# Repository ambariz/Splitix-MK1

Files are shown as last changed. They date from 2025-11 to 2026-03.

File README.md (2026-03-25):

# Splitix MK1

A custom, split mechanical keyboard with modular design, it can be used as a split keyboard or joined together and used like a regular keyboard.

Inspired by the split, futuristic keyboard used by Tony Stark in Iron Man, this project explores that concept in a practical, physical form. Splitix MK1 is the first iteration, focused on building a solid foundation before moving towards more advanced designs.

It features a custom PCB designed in KiCad, per-key NeoPixel RGB lighting, an integrated display, and a rotary encoder. The board also includes battery support with voltage monitoring.

The design includes a fully hand-routed PCB with custom footprints and a skeletal 3D-printed case that enhances the lighting and overall aesthetic.

This project is part of a larger journey toward creating a more advanced, Iron Man - inspired keyboard in future iterations.

| Left Build (without case) | Right Build (without case) |
|---|---|
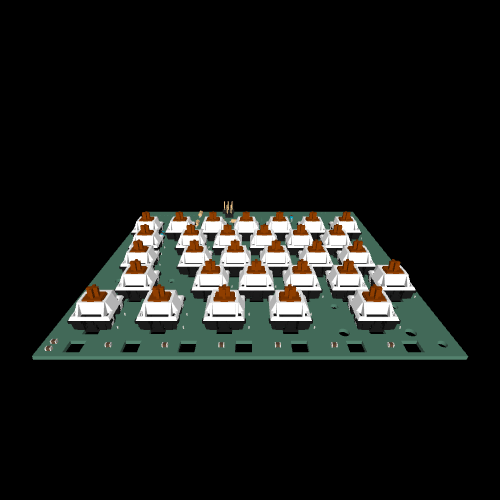
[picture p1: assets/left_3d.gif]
left build
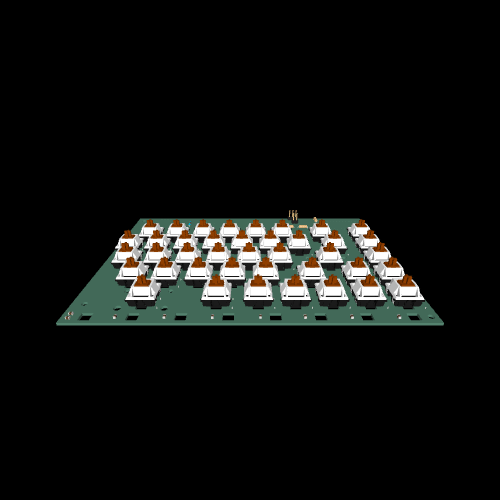
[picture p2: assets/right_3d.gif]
right build
|  |  |

# Features

- Split / Modular (can be joined and used as a single keyboard)
- Wireless (Bluetooth via NRF52840)
- ZMK Firmware
- Hotswappable
- Per-key NeoPixel RGB
- Rotary Encoder
- Integrated Display
- Skeletal 3D-printed case (M3 mount)

## CAD

> **Note:**
> This is a skeletal open case design that includes only the base structure. It is designed to hold the PCB securely while keeping the overall form minimal and exposing the components, especially the RGB lighting. The open design enhances visibility of the internals and lighting, while support pillars and M3 mounts provide the necessary structural stability.

| Left | Right |
|---|---|
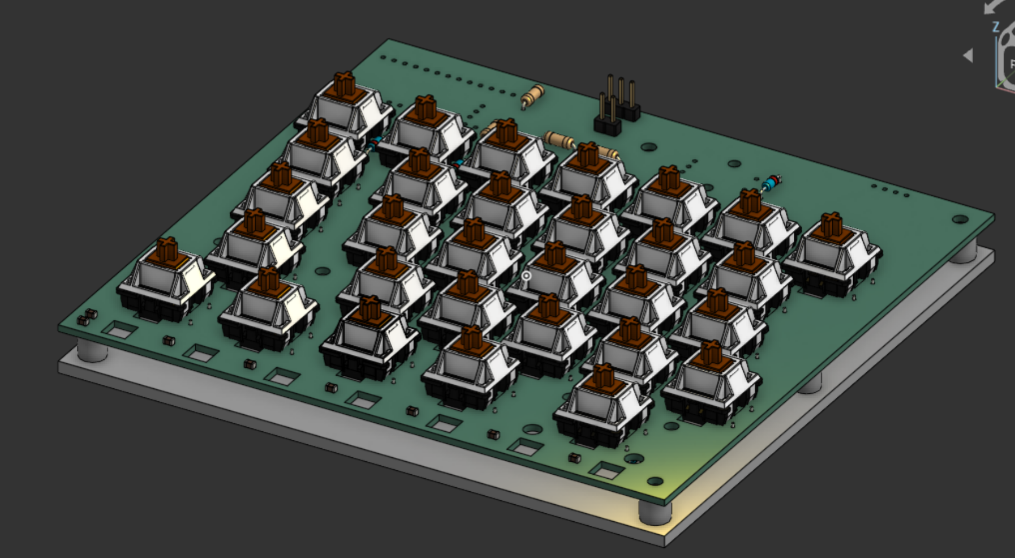
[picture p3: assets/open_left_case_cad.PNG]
case left
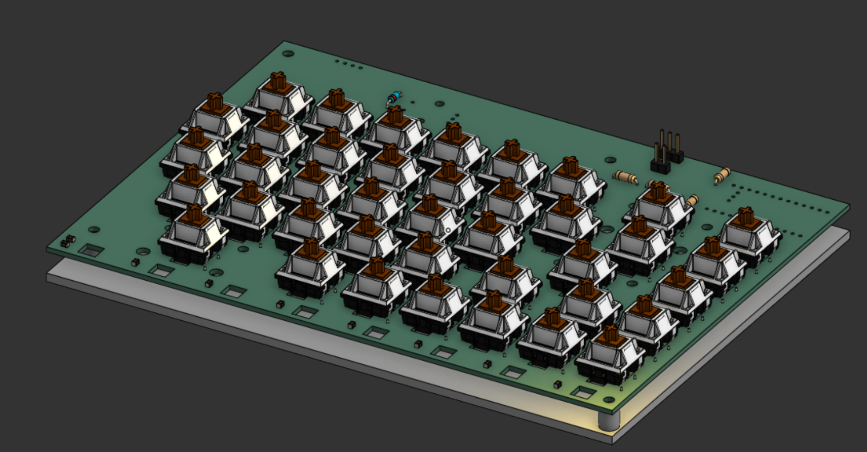
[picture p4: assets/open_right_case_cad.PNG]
case right
|  |  |
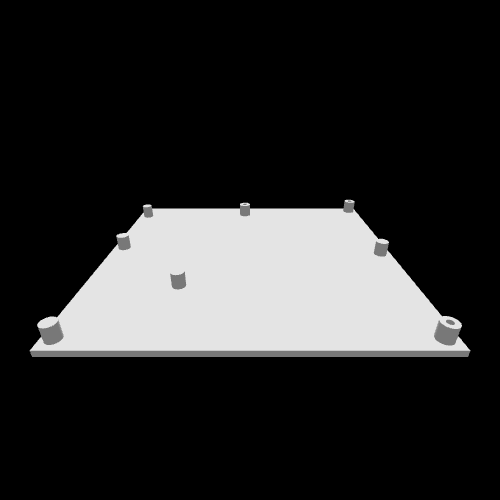
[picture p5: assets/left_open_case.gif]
case left
|  | case right |
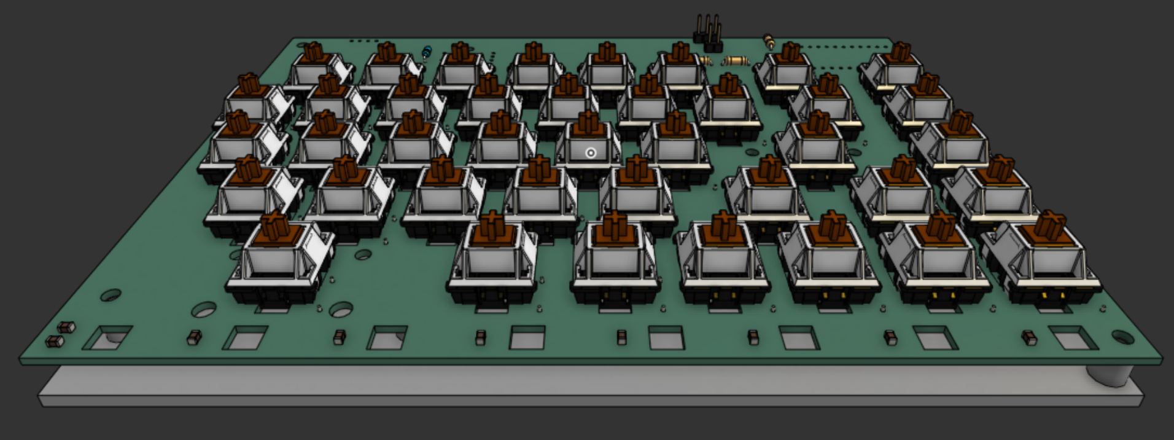
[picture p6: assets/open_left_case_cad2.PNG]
case left
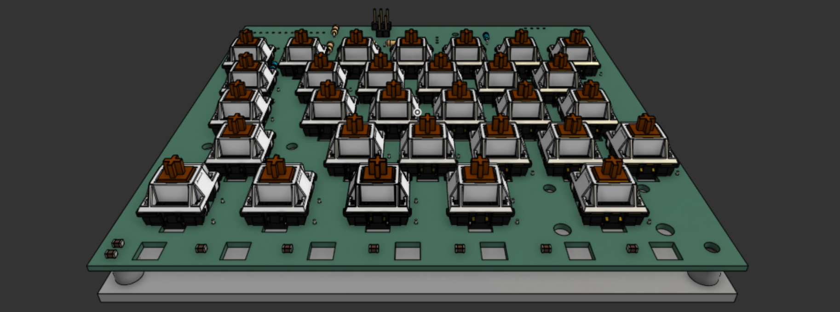
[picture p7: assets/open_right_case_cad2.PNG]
case right
|  |  |

## PCB

> **Note:**  
> The PCB is designed as a single board with mouse bite connections, allowing it to be snapped into left and right halves after fabrication.

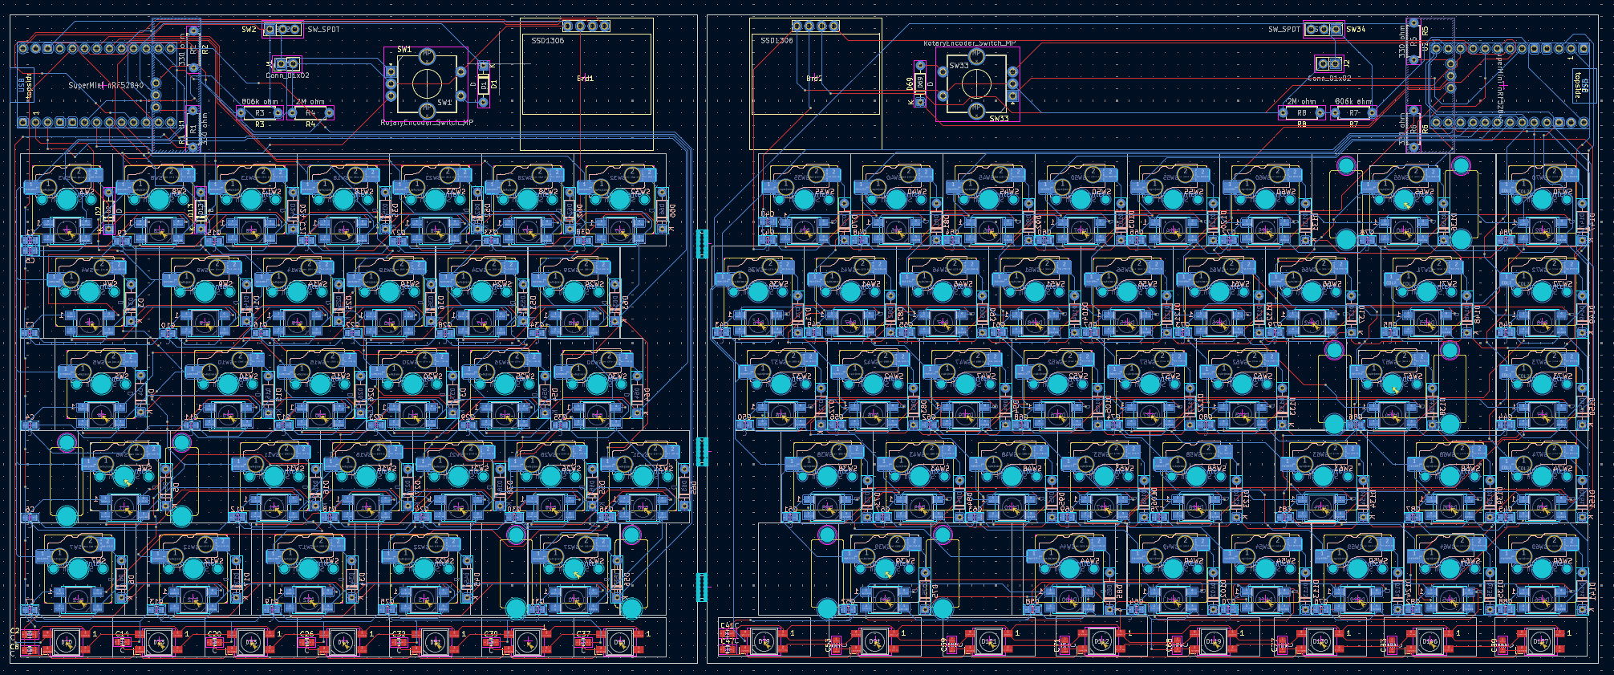
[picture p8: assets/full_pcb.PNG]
PCB


## Schematic

> **Note:**  
> The preview images may be scaled down and lose detail. Use the PDF below for a clear, full-resolution view.

<p align="center">
  <a href="https://raw.githubusercontent.com/ambariz/Splitix-MK1/main/pcb/Splitix%20MK1.pdf">
    
  </a>
</p>

| Left | Right |
|---|---|
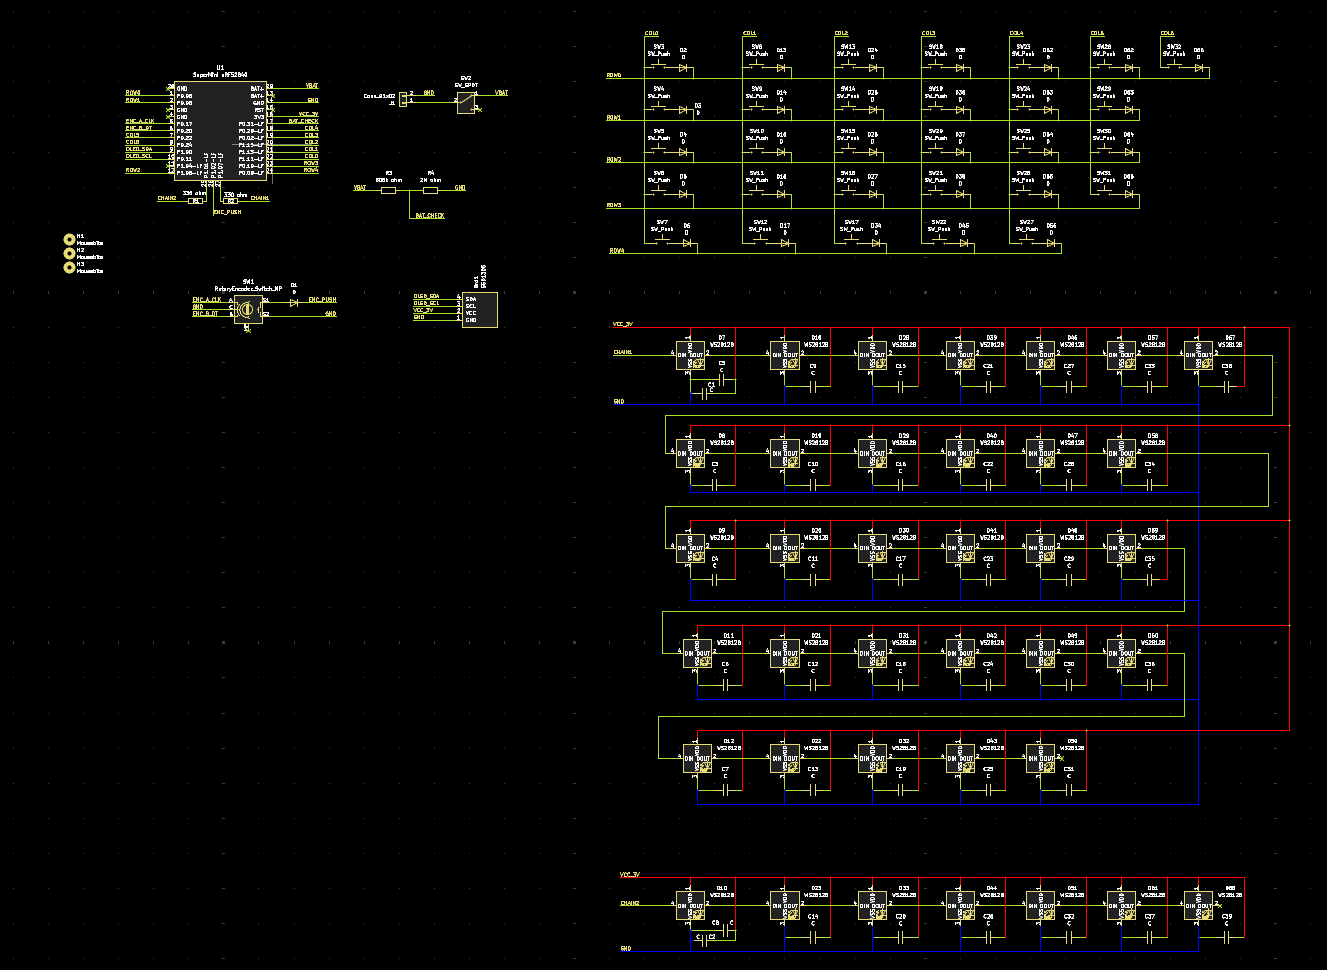
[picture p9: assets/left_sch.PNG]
Left schematic
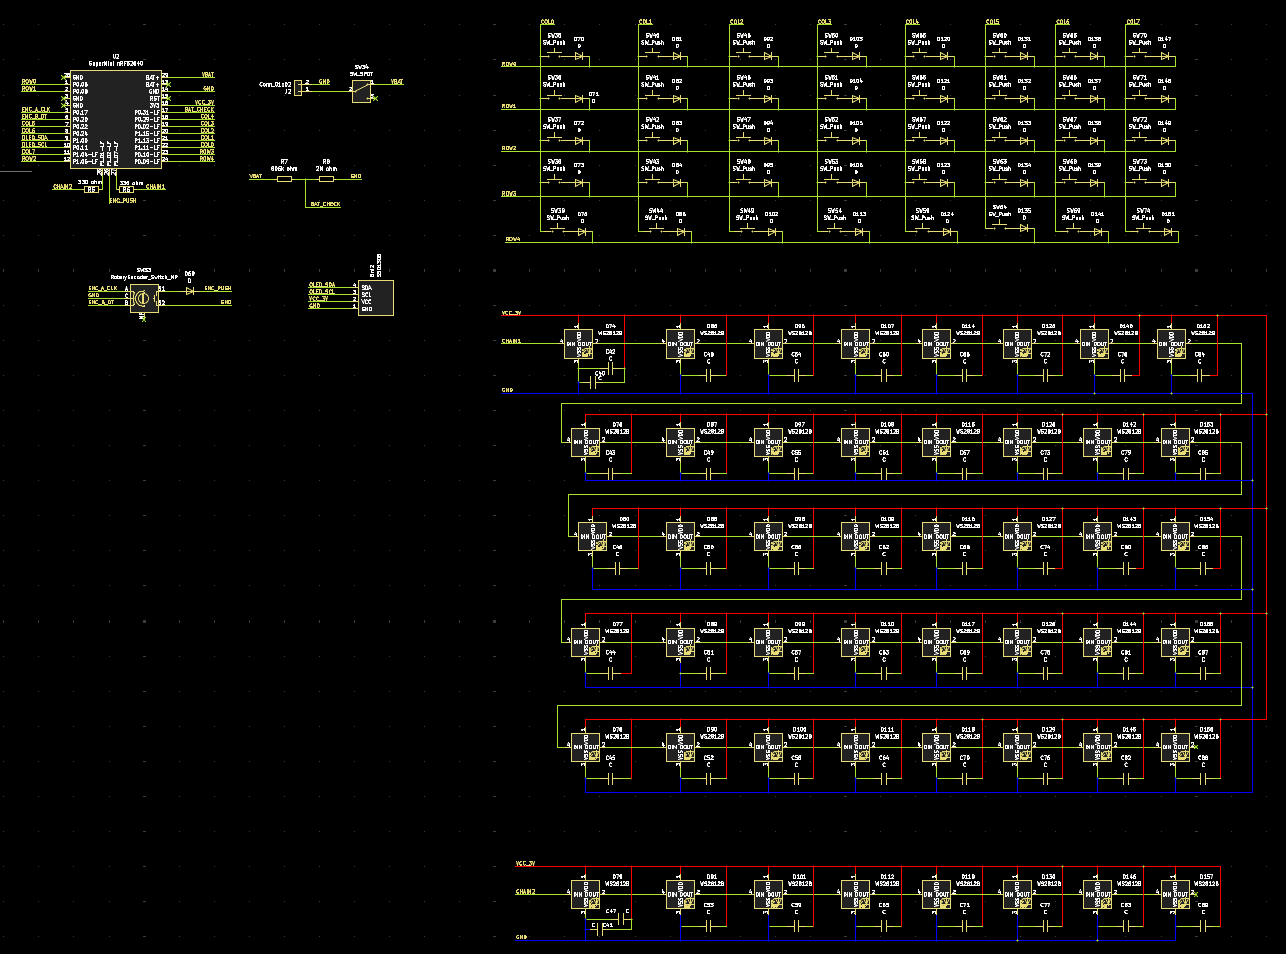
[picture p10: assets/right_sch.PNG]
Right schematic
|  |  |

## ZMK Keymap

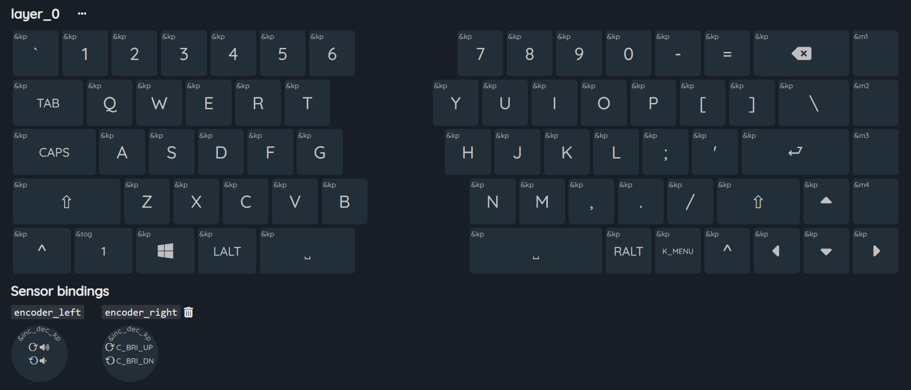
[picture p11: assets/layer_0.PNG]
layer 0

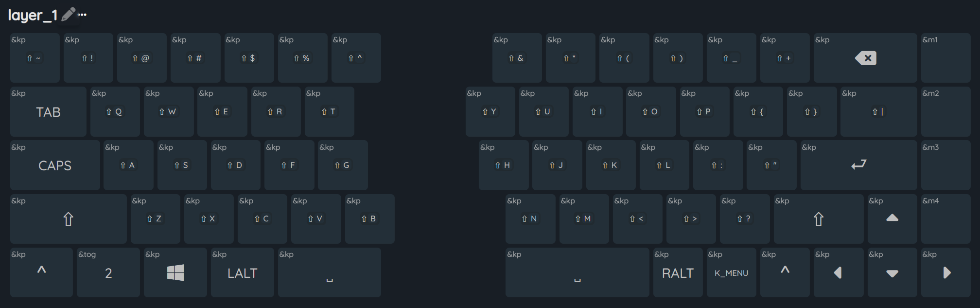
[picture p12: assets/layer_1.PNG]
layer 1

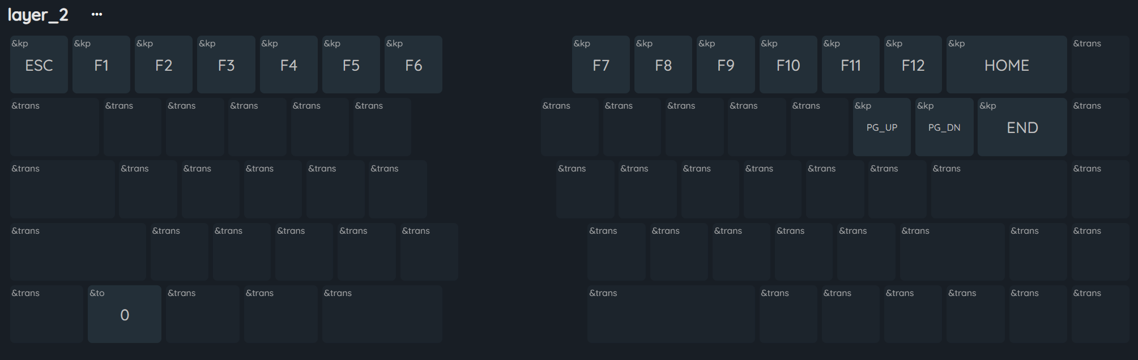
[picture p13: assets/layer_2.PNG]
layer 2


## BOM

| Product | Quantity | Source | Price (INR) | Link |
| :--- | :--- | :--- | :--- | :--- |
| ProMicro NRF52840 | 2 | Robu | 1516 | [Product Link](https://robu.in/product/promicro-nrf52840-development-board/) <br> OR <br> [Product Link](https://robu.in/product/pro-micro-nrf52840-development-board-compatible-with-nicenano-v2-0/) <br> OR <br> [Product Link](https://probots.co.in/pro-micro-nrf52840-development-board-compatible-with-nice-nano-v2-0.html)|
| Hongyan EC11H 7CE20P1ZD20 | 2 | Robu | 110 | [Product Link](https://robu.in/product/hongyan-ec11h-7ce20p1zd20-rotary-encoder-with-push-button-switch-vertical-plug-in-5-pin/) |
| EC11 Rotary Encoder Knob (D-shaft) | 2 | Robu | 58 | [Product Link](https://robu.in/product/potentiometer-knob-rotary-switch-cap-black-color-pack-of-5-pcs/) |
| 0.96" / 1.3" I2C OLED | 2 | Robu | 312 | [Product Link](https://robu.in/product/0-96-inch-yellow-yellow-blue-oled-lcd-led-display-module/) <br> OR <br> [Product Link](https://robu.in/product/1-3-inch-i2c-iic-4-pin-oled-display-module-with-vcc-gnd-blue/) |
| WS2812B 16-LED Ring (Neopixel) | 6 (rings) / 90 (individual) | Robu / Ktron | 546 | [Product Link](https://robu.in/product/16bit-ws2812b-5050-rgb-led-built-in-full-color-driving-lights-circular-development-board/) <br> OR <br> [Product Link](https://www.ktron.in/product/ws2812b-rgb-smd-5050-led/?v=c86ee0d9d7ed) |
| 330Ω Resistor | 4 | Robu | 1.16 | [Product Link](https://robu.in/product/330-ohm-0-25w-metal-film-resistor-pack-of-100/) |
| 806kΩ Resistor | 2 | Robu | 1.24 | [Product Link](https://robu.in/product/mcmf0w4ff8203a50-multicomp-pro-metal-film-resistor-820kohm-250mw-1/) |
| 2MΩ Resistor | 2 | Amazon | 198 | [Product Link](https://www.amazon.in/Electronic-Spices-Tolerance-Through-Resistors/dp/B0BDDRD9DN) |
| 100µF 0805 Capacitor | 6 | Robu | 270 | [Product Link](https://robu.in/product/cl21a107mqynnwe-samsang-6-3v-100uf-x5r-%C2%B120-0805-multilayer-ceramic-capacitors-mlcc-smd-smt-rohs/) |
| 0.1µF (100nF) 0805 Capacitor | 95 | Robu | 145.35 | [Product Link](https://robu.in/product/cc0805jrx7r9bb104-yageo-smd-multilayer-ceramic-capacitor-0-1-%C2%B5f-50-v-0805-2012-metric-%C2%B1-5-x7r-cc-series/) |
| Mechanical Key Switches (MX Compatible) | 75 | StacksKB | 2398 | [Product Link](https://stackskb.com/store/akko-creamy-cyan-switch-pack-of-45-pre-order/) |
| Keycaps (MX Compatible) | 1 set | StacksKB | 1299 | [Product Link](https://stackskb.com/store/veekos-gradient-keycaps-cherry-profile-135-keys/) |
| Hotswap Sockets (Kailh MX) | 75 | StacksKB | 750 | [Product Link](https://stackskb.com/store/ttc-pokayoke-hotswap-sockets-v2-10000-cycles/) |
| 1N4148 Diodes | 80 | StacksKB | 120 | [Product Link](https://stackskb.com/store/1n4148-through-hole-diode/) |
| Li-ion Battery 1500mAh | 2 | Robu | 502 | [Product Link](https://robu.in/product/nova-803450-1500mah-3-7v-lipo-battery-pack/) |
| JST-PH 2-pin Connector | 2 | Robu | 2.84 | [Product Link](https://robu.in/product/jst-sh-2-pin-connector-2mm-pitch/) |
| TP4056 Type-C Charging Module | 2 | Robu | 28 | [Product Link](https://robu.in/product/tp4056-1a-li-ion-lithium-battery-charging-module-with-current-protection-type-c/) |
| Slide Switch SS-12D03 | 2 | Robu | 6 | [Product Link](https://robu.in/product/slide-switch-ss-12d03-1p2t/) |
| Keyboard PCB Left | 5 | Robu | 2500 | [Product Link](https://robu.in/product/online-pcb-manufacturing-service/) |
| Keyboard PCB Right | 5 | Robu | 2500 | [Product Link](https://robu.in/product/online-pcb-manufacturing-service/) |
| Keyboard Case (3D Print) | 1 | Robu | 530 | [Product Link](https://robu.in/product/3d-printing-service/) |
| Screws | 15 | Generic |  | Any M3 screws will work |

---

### Total Cost (Maximum)

**₹13,793.59**

> Includes all components for full build.

---

# Mechanical Keyboard Keycap Profiles
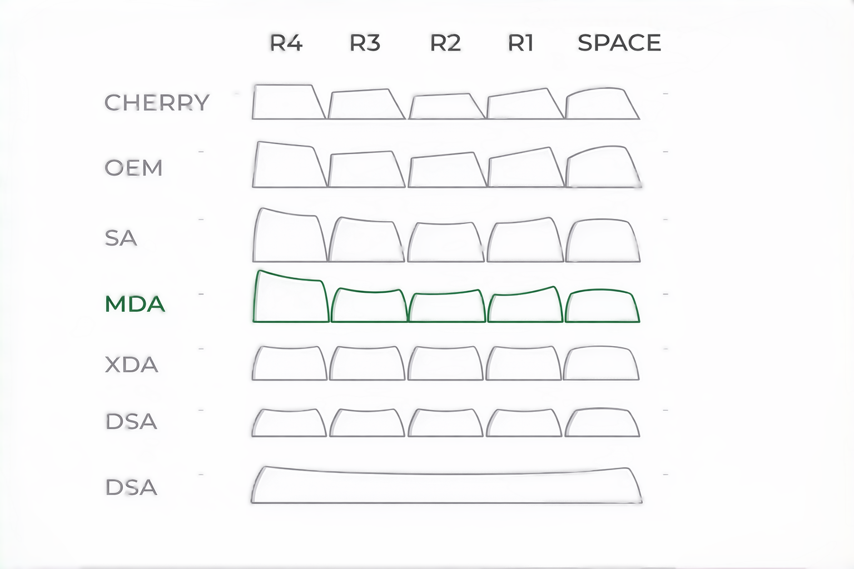
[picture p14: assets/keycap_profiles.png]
Mechanical Keyboard Keycap Profiles Comparison


---

### Quick Comparison
| Profile | Key Features | Best Used For |
| :--- | :--- | :--- |
| **Cherry** | Ergonomic height, reduces accidental touches. | All-around daily use. |
| **OEM** | Standard height, crisp typing sound. | Linear switches and gaming. |
| **XDA** | Uniform height, large surface area. | Tactile switches, long typing sessions. |
| **DSA** | Very low, uniform height. | Minimalist builds and customization. |
| **MDA** | Stepped uniform profile, textured feel. | Ergonomic long-form typing. |
| **SA** | Tallest profile, spherical sculpt. | Aesthetics and deep sound (requires wrist rest). |

---

> ### Note:
- **Tall Profiles (SA):** Better acoustics and aesthetics, but poor ergonomics without a wrist rest.  
- **Flat Profiles (XDA, DSA):** Easier to customize looks, but higher chance of mistyping.  
- **Sculpted Profiles (Cherry, OEM, MDA):** Best for typing speed and overall accuracy.  

---

# Keyswitch Selection Guide

| Type | Characteristics | Best For |
| :--- | :--- | :--- |
| **1️⃣ Linear** | Very smooth, no bump. Quiet unless bottom-out → nice thock | Gaming + smooth typing |
| **2️⃣ Tactile** | Noticeable bump mid-press. Balanced sound + feel | Typing |
| **3️⃣ Clicky** | Loud click + tactile bump. Very audible → polarizing | Enthusiasts who love feedback |
| **4️⃣ Low Profile** | Short travel → less thock. More functional than aesthetic | Portable/compact builds |
| **5️⃣ Silent Switches** | Dampened + muted. Almost no sound → office safe | Office environments |  

marbastlib
keyswitch kicad library
keyboard footprints placer
fabrucatuib toolkit

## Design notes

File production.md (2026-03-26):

# Production - Splitix MK1

## Production Files

### PCB (Gerbers)

* `gerber_left.zip` – Left half PCB
* `gerber_right.zip` – Right half PCB
* `gerber_full.zip` – Panelized full PCB

### Case (3D Models)

* `left_open_case.3mf` / `left_open_case.stl`
* `right_open_case.3mf` / `right_open_case.stl`
* `full_open_case.3mf` / `full_open_case.stl`

---

## Which Files Should You Use?

### PCB

> *NOTE:*
> full gerber or left and right gerber costs will be same. full gerber got mousebites, you can easily break in to left and right pcb.

* Printing seperately or any one side → `gerber_left.zip` + `gerber_right.zip`
* Printing both → `gerber_full.zip`

### Case

* Split case → left + right files
* Single-piece case → full files

### Other Formats

* Other fomates are in ```cad/3d_printing```

> *NOTE:*
> All formats contain the same models. You only need one.

---

## PCB Manufacturing

1. Go to any PCB manufacturer (JLCPCB, PCBWay, etc.)

2. Upload:
   ```
   gerber_left.zip
   gerber_right.zip
   ```
   or:
   ```
   gerber_full.zip
   ```
---

## Source Files
For modifications:
* PCB design → `/pcb/`
* Case models → `/cad/`
---
## Summary
* Use Gerber files to manufacture PCBs
* Use STL or 3MF files to print cases
* Choose split or full configuration based on your build
---

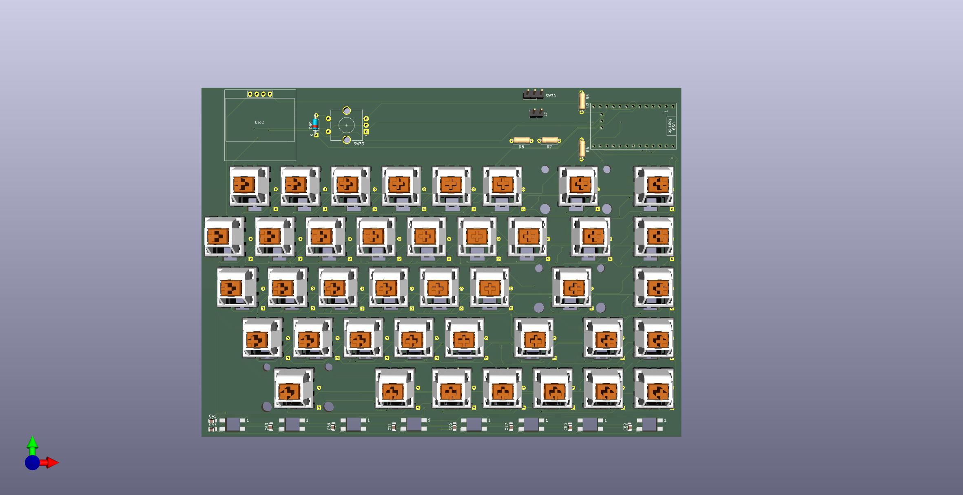
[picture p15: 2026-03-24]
assets/right_3d.png

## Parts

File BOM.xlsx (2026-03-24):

Product | Quantity | Source | Price (INR) | Link | Total
ProMicro NRF52840 | 2 | Robu | 758 | Product Link (https://robu.in/product/promicro-nrf52840-development-board/) | 1516
 |  |  |  | OR
 |  |  |  | Product Link (https://robu.in/product/pro-micro-nrf52840-development-board-compatible-with-nicenano-v2-0/)
 |  |  |  | OR
 |  |  |  | Product Link (https://probots.co.in/pro-micro-nrf52840-development-board-compatible-with-nice-nano-v2-0.html)
Hongyan EC11H 7CE20P1ZD20 | 2 | Robu | 55 | Product Link (https://robu.in/product/hongyan-ec11h-7ce20p1zd20-rotary-encoder-with-push-button-switch-vertical-plug-in-5-pin/) | 110
EC11 Rotary Encoder Knob | 2 | Robu | 29 | Product Link (https://robu.in/product/potentiometer-knob-rotary-switch-cap-black-color-pack-of-5-pcs/) | 58
OLED Display (0.96 / 1.3 I2C) | 2 | Robu | 156 | Product Link (https://robu.in/product/0-96-inch-yellow-yellow-blue-oled-lcd-led-display-module/) | 312
WS2812B LEDs (Ring) | 6 (rings) or 90 (individual) | Robu | 91 | Product Link (https://robu.in/product/16bit-ws2812b-5050-rgb-led-built-in-full-color-driving-lights-circular-development-board/) | 546
330Ω Resistors | 4 | Robu | 0.29 | Product Link (https://robu.in/product/330-ohm-0-25w-metal-film-resistor-pack-of-100/) | 1.16
806kΩ Resistors | 2 | Robu | 0.62 | Product Link (https://robu.in/product/mcmf0w4ff8203a50-multicomp-pro-metal-film-resistor-820kohm-250mw-1/) | 1.24
2MΩ Resistors | 2 | Amazon | 99 | Product Link (https://www.amazon.in/Electronic-Spices-Tolerance-Through-Resistors/dp/B0BDDRD9DN) | 198
100µF Capacitors (0805) | 6 | Robu | 45 | Product Link (https://robu.in/product/cl21a107mqynnwe-samsang-6-3v-100uf-x5r-%C2%B120-0805-multilayer-ceramic-capacitors-mlcc-smd-smt-rohs/) | 270
0.1µF Capacitors (0805) | 95 | Robu | 1.53 | Product Link (https://robu.in/product/cc0805jrx7r9bb104-yageo-smd-multilayer-ceramic-capacitor-0-1-%C2%B5f-50-v-0805-2012-metric-%C2%B1-5-x7r-cc-series/) | 145.35
MX Mechanical Switches | 75 (2 sets) | Stackskb | 1199.00 | Product Link (https://stackskb.com/store/akko-creamy-cyan-switch-pack-of-45-pre-order/) | 2398
Keycaps (MX Compatible) | 1 set | Stackskb | 1299.00 | Product Link (https://stackskb.com/store/veekos-gradient-keycaps-cherry-profile-135-keys/) | 1299.00
Hotswap Sockets (Kailh MX) | 75 | Stackskb | 10 | Product Link (https://stackskb.com/store/ttc-pokayoke-hotswap-sockets-v2-10000-cycles/) | 750
Diodes (1N4148) | 8 x 10/pack (80 nos) | Stackskb | 15 | Product Link (https://stackskb.com/store/1n4148-through-hole-diode/) | 120
Li-ion Battery | 2 | Robu | 251 | Product Link (https://robu.in/product/nova-803450-1500mah-3-7v-lipo-battery-pack/) | 502
Battery Connector (JST-SH 2-pin) | 2 | Robu | 1.42 | Product Link (https://robu.in/product/jst-sh-2-pin-connector-2mm-pitch/) | 2.84
TP4056 Charging Module | 2 | Robu | 14 | Product Link (https://robu.in/product/tp4056-1a-li-ion-lithium-battery-charging-module-with-current-protection-type-c/) | 28
Slide Switch (SS-12D03) | 2 | Robu | 3 | Product Link (https://robu.in/product/slide-switch-ss-12d03-1p2t/) | 6
PCB (Left + Right) | 5 left + 5 right | Robu | 5000 | Product Link (https://robu.in/product/online-pcb-manufacturing-service/) | 5000
Case (3D Printed) | 1 | Robu | 530 | Product Link (https://robu.in/product/3d-printing-service/) | 530
Screws | 1 | Local
 |  |  |  | TOTAL | 13793.59

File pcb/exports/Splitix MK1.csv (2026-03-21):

# | Reference | Qty | Value | Footprint | DNP
1 | Brd1, Brd2 | 2 | SSD1306 | SSD1306-128x64_OLED:128x64OLED
2 | C1, C2, C3, C4, C5, C6, C7, C8, C9, C10, C11, C12, C13, C14, C15, C16, C17, C18, C19, C20, C21, C22, C23, C24, C25, C26, C27, C28, C29, C30, C31, C32, C33, C34, C35, C36, C37, C38, C39, C40, C41, C42, C43, C44, C45, C46, C47, C48, C49, C50, C51, C52, C53, C54, C55, C56, C57, C58, C59, C60, C61, C62, C63, C64, C65, C66, C67, C68, C69, C70, C71, C72, C73, C74, C75, C76, C77, C78, C79, C80, C81, C82, C83, C84, C85, C86, C87, C88, C89 | 89 | C | Capacitor_SMD:C_0805_2012Metric_Pad1.18x1.45mm_HandSolder
3 | D1, D2, D3, D4, D5, D6, D13, D14, D15, D16, D17, D24, D25, D26, D27, D34, D35, D36, D37, D38, D45, D52, D53, D54, D55, D56, D62, D63, D64, D65, D66, D69, D70, D71, D72, D73, D75, D81, D82, D83, D84, D85, D92, D93, D94, D95, D102, D103, D104, D105, D106, D113, D120, D121, D122, D123, D124, D131, D132, D133, D134, D135, D136, D137, D138, D139, D141, D147, D148, D149, D150, D151 | 72 | D | Diode_THT:D_DO-35_SOD27_P7.62mm_Horizontal
4 | D7, D8, D9, D11, D12, D18, D19, D20, D21, D22, D28, D29, D30, D31, D32, D39, D40, D41, D42, D43, D46, D47, D48, D49, D50, D57, D58, D59, D60, D67, D74, D76, D77, D78, D80, D86, D87, D88, D89, D90, D96, D97, D98, D99, D100, D107, D108, D109, D110, D111, D114, D115, D116, D117, D118, D125, D126, D127, D128, D129, D140, D142, D143, D144, D145, D152, D153, D154, D155, D156 | 70 | WS2812B | WS2812B_5050_SMD_REVERSED :WS2812B_5050_reversed_SMD_edge
5 | D10, D23, D33, D44, D51, D61, D68, D79, D91, D101, D112, D119, D130, D146, D157 | 15 | WS2812B | WS2812B_5050_SMD_REVERSED :WS2812B_5050_reversed_SMD_strip
6 | J1, J2 | 2 | Conn_01x02 | Connector_PinHeader_2.54mm:PinHeader_1x02_P2.54mm_Vertical
7 | R1, R2, R5, R6 | 4 | 330 ohm | Resistor_THT:R_Axial_DIN0207_L6.3mm_D2.5mm_P7.62mm_Horizontal
8 | R3, R7 | 2 | 806k ohm | Resistor_THT:R_Axial_DIN0207_L6.3mm_D2.5mm_P7.62mm_Horizontal
9 | R4, R8 | 2 | 2M ohm | Resistor_THT:R_Axial_DIN0207_L6.3mm_D2.5mm_P7.62mm_Horizontal
10 | SW1, SW33 | 2 | RotaryEncoder_Switch_MP | Rotary_Encoder:RotaryEncoder_Alps_EC11E-Switch_Vertical_H20mm_CircularMountingHoles
11 | SW2, SW34 | 2 | SW_SPDT | Connector_PinHeader_2.54mm:PinHeader_1x03_P2.54mm_Vertical
12 | SW3, SW8, SW9, SW10, SW11, SW13, SW14, SW15, SW16, SW18, SW19, SW20, SW21, SW23, SW24, SW25, SW26, SW28, SW29, SW30, SW31, SW32, SW35, SW36, SW37, SW38, SW40, SW41, SW42, SW43, SW45, SW46, SW47, SW48, SW49, SW50, SW51, SW52, SW53, SW54, SW55, SW56, SW57, SW58, SW59, SW60, SW61, SW62, SW64, SW66, SW68, SW69, SW70, SW72, SW73, SW74 | 56 | SW_Push | PCM_marbastlib-xp-mx:SW_MX_HS_KS-2P02B01-01_1u
13 | SW4, SW71 | 2 | SW_Push | PCM_marbastlib-xp-mx:SW_MX_HS_KS-2P02B01-01_1.5u
14 | SW5, SW63 | 2 | SW_Push | PCM_marbastlib-xp-mx:SW_MX_HS_KS-2P02B01-01_1.75u
15 | SW6, SW67 | 2 | SW_Push | PCM_marbastlib-xp-mx:SW_MX_HS_KS-2P02B01-01_2.25u
16 | SW7, SW12, SW17, SW22, SW44 | 5 | SW_Push | PCM_marbastlib-xp-mx:SW_MX_HS_KS-2P02B01-01_1.25u
17 | SW27, SW65 | 2 | SW_Push | PCM_marbastlib-xp-mx:SW_MX_HS_KS-2P02B01-01_2u
18 | SW39 | 1 | SW_Push | PCM_marbastlib-xp-mx:SW_MX_HS_KS-2P02B01-01_2.75u

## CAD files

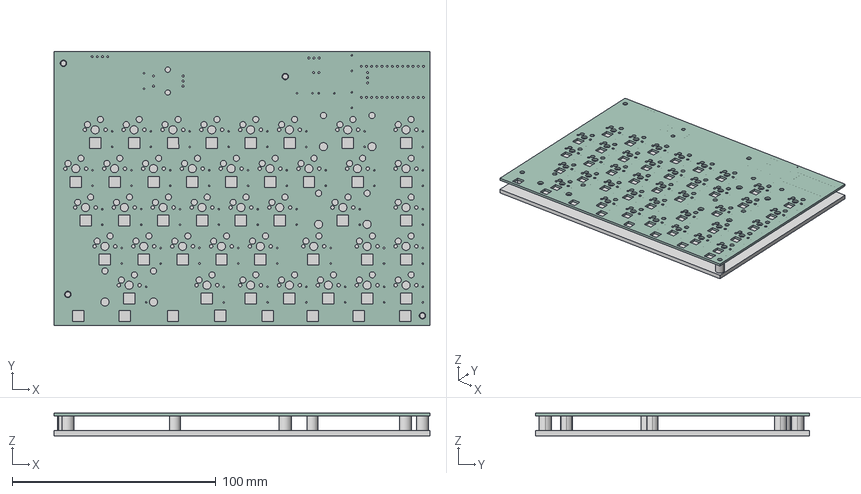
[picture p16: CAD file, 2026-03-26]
assembly/right_assembled.step
184.4 x 134.1 x 11.2 mm

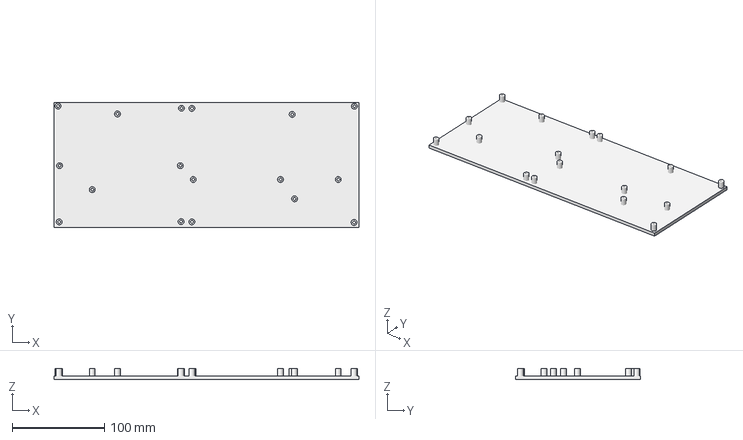
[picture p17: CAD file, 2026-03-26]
production/full_case/full_open_case.3mf
331.0 x 136.0 x 12.0 mm

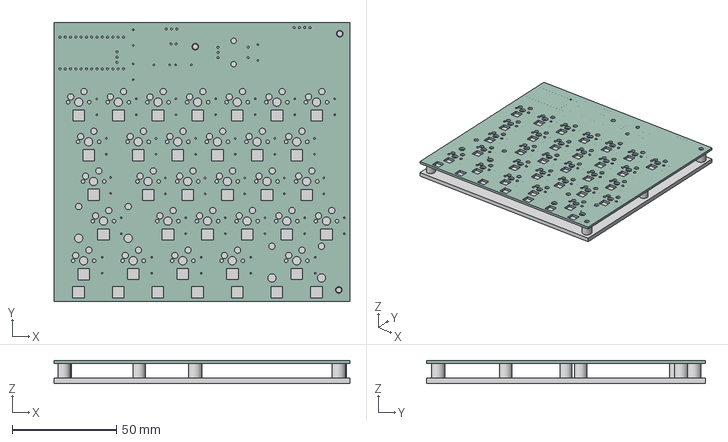
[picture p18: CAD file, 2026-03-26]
assembly/left_assembled.step
142.2 x 134.2 x 11.2 mm

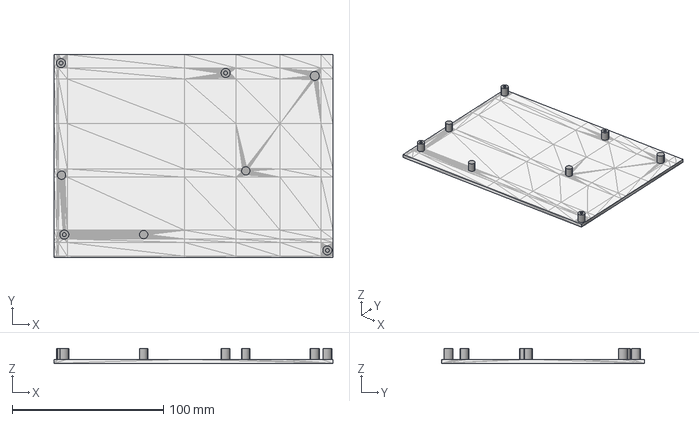
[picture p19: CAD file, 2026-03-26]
cad/3d_printing/right_open_case.step
184.4 x 134.1 x 9.70 mm

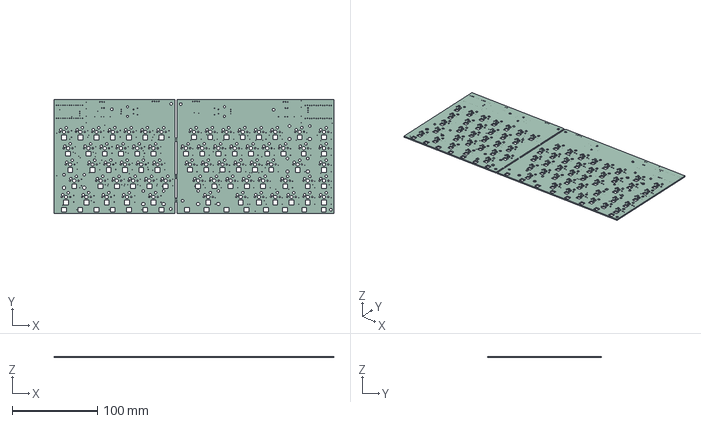
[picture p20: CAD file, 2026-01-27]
pcb/exports/Splitix MK1.step
328.2 x 134.0 x 1.51 mm

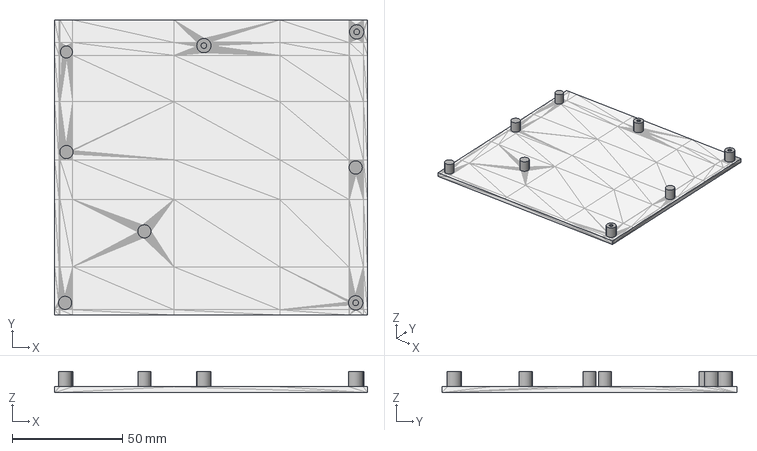
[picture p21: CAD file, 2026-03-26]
production/left_case/left_open_case.step
142.2 x 134.2 x 9.70 mm

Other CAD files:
cad/3d_models/Splitix_MK1_only_case.stl
production/right_case/right_open_case.step
cad/3d_printing/left_open_case.step
production/full_case/full_open_case.stl
production/left_case/left_open_case.3mf
production/left_case/left_open_case.stl
production/right_case/right_open_case.3mf
production/right_case/right_open_case.stl

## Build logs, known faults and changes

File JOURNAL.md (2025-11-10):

<!--
  ===================    !!READ THIS NOTICE!!   ====================
  DO NOT edit this file manually. Your changes WILL BE OVERWRITTEN!
  This journal is auto generated and updated by Hack Club Blueprint.
  To edit this file, please edit your journal entries on Blueprint.
  ==================================================================
-->

## 11/6/2025 - Learned and did a circuit diagram.  

I watched, read and made a circuit diagram in kicad 9.0

I watched many videos and learned about how keyboards work, how they are made. And learned about the matrix structure, and what are the uses of diode.

Splitix MK1 is a split keyboard (like Ironman's one) so today I did circuit diagram of matrix and connected it.

I learned about the MCUs, but not sure, which one to use.

Screenshot from 2025-11-06 23-18-43

## 11/9/2025 12 PM - Selected controller, gathered all components  

This journal is for yesterday and today's drawing

I learned about controller for Splitix, by asking in slack and learning in youtube. and selected the controller.

But after selecting the controller, it was not there in kicad so i searched for long time and atlast i got the right circuit and foot print for pro micro.

And learned about neopixels ( it's led but it has it's own brain ) and added encoder, display.

second journal

And I drew the keyboard by hand in paper to fix the keys, I didn't connect the circuit yet, I will do it in evening.

paper drawing

## 11/9/2025 11 PM - Connected everything, now circuit is complete  

Today I connected all the components.

I learned that not every component can be connected in any pin, every pin has it's own work.

I added capacitor for each and every pixel and two capacitors. And two capacitors in starting of the neopixel for more filter.

capacitors are like filter for tea

Connecting everything is very hard, It was confusing but i used different colours for it, 

like red for vcc, blue for gnd, green for others 

3 journal

I think now the circuit is completed.  

## 11/10/2025 - Added Battery, Changed few pins on circuit  

I learned how to add battery to this circuit, and how to check battery percentage using voltage divider.

There is a formula for voltage divider.

using that formula we can calculate the remaining battery. 

First I connected the voltage divider in normal pin but after learning a bit more, it should in a pin with a work called ADC which means analog to digital converter.

And I put X in unused pins, because kicad thinks it's a problem.

I can't say the circuit is over, yesterday I thought the circuit was over but today I made changes.

This is current circuit. (without matrix and leds) ( and I changed the Kicad theme too )

4 journal

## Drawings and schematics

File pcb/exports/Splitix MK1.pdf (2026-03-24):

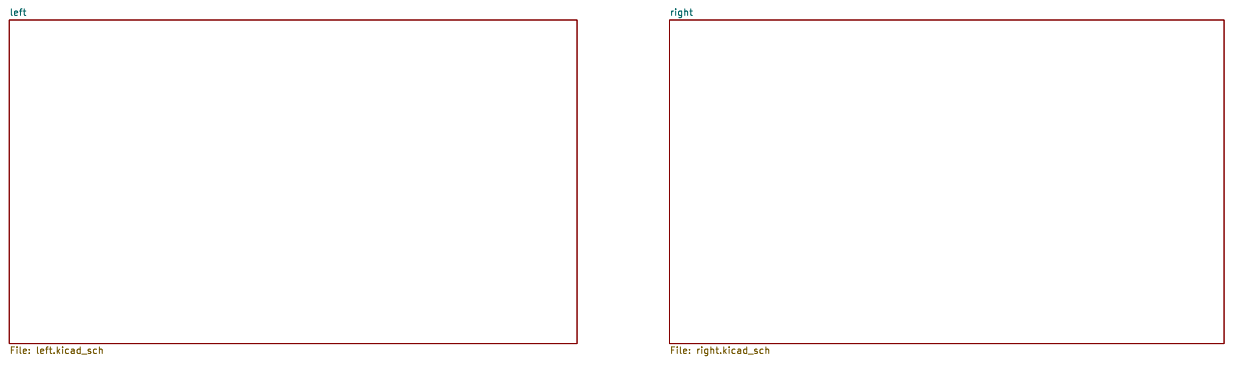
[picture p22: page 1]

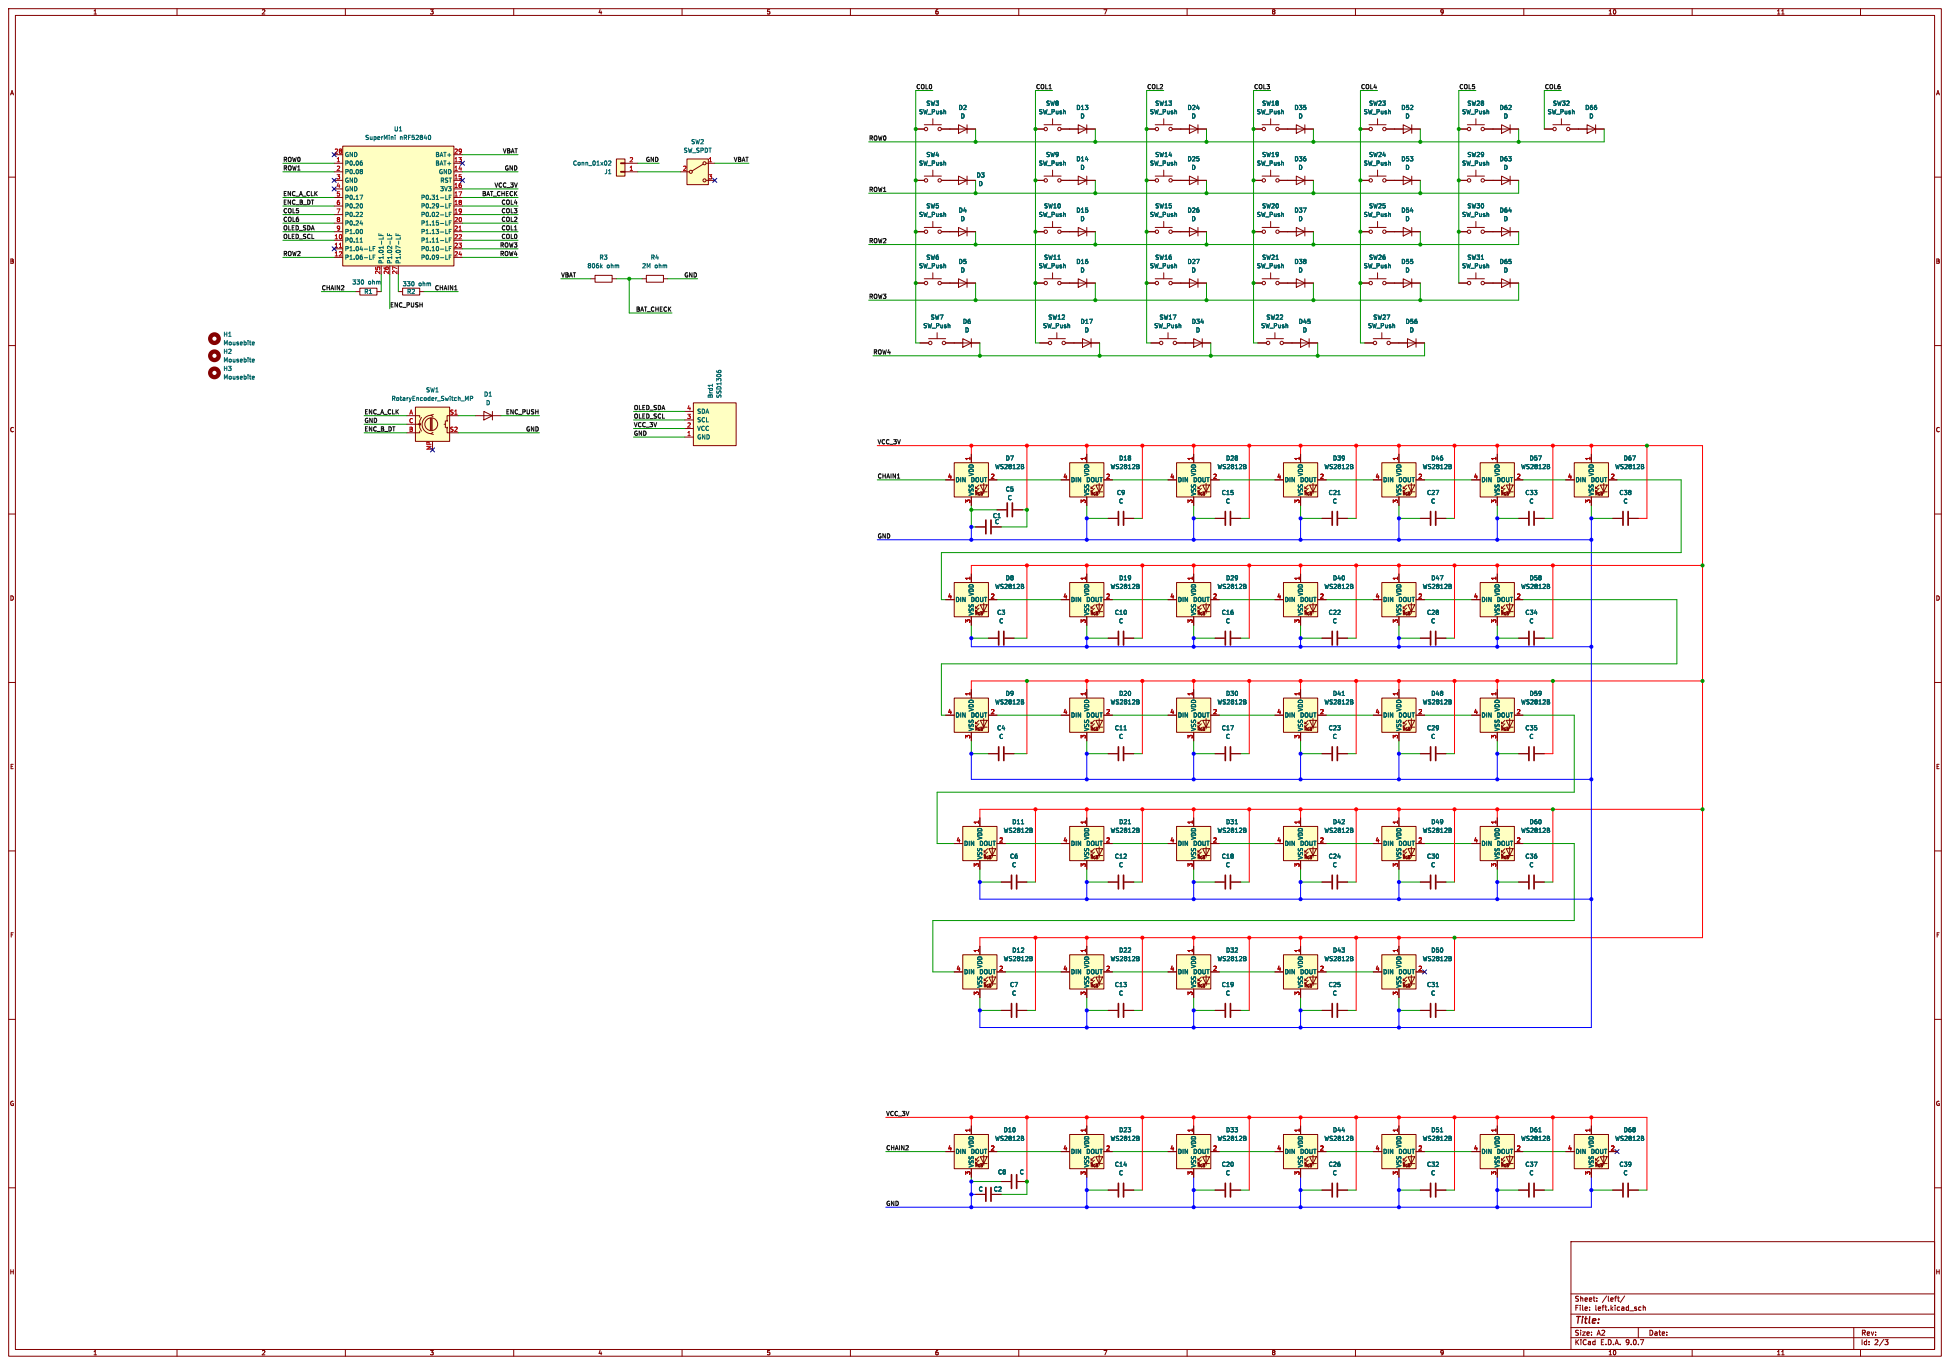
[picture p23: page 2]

Id: 2/3 Title: File: left.kicad_sch Sheet: /left/

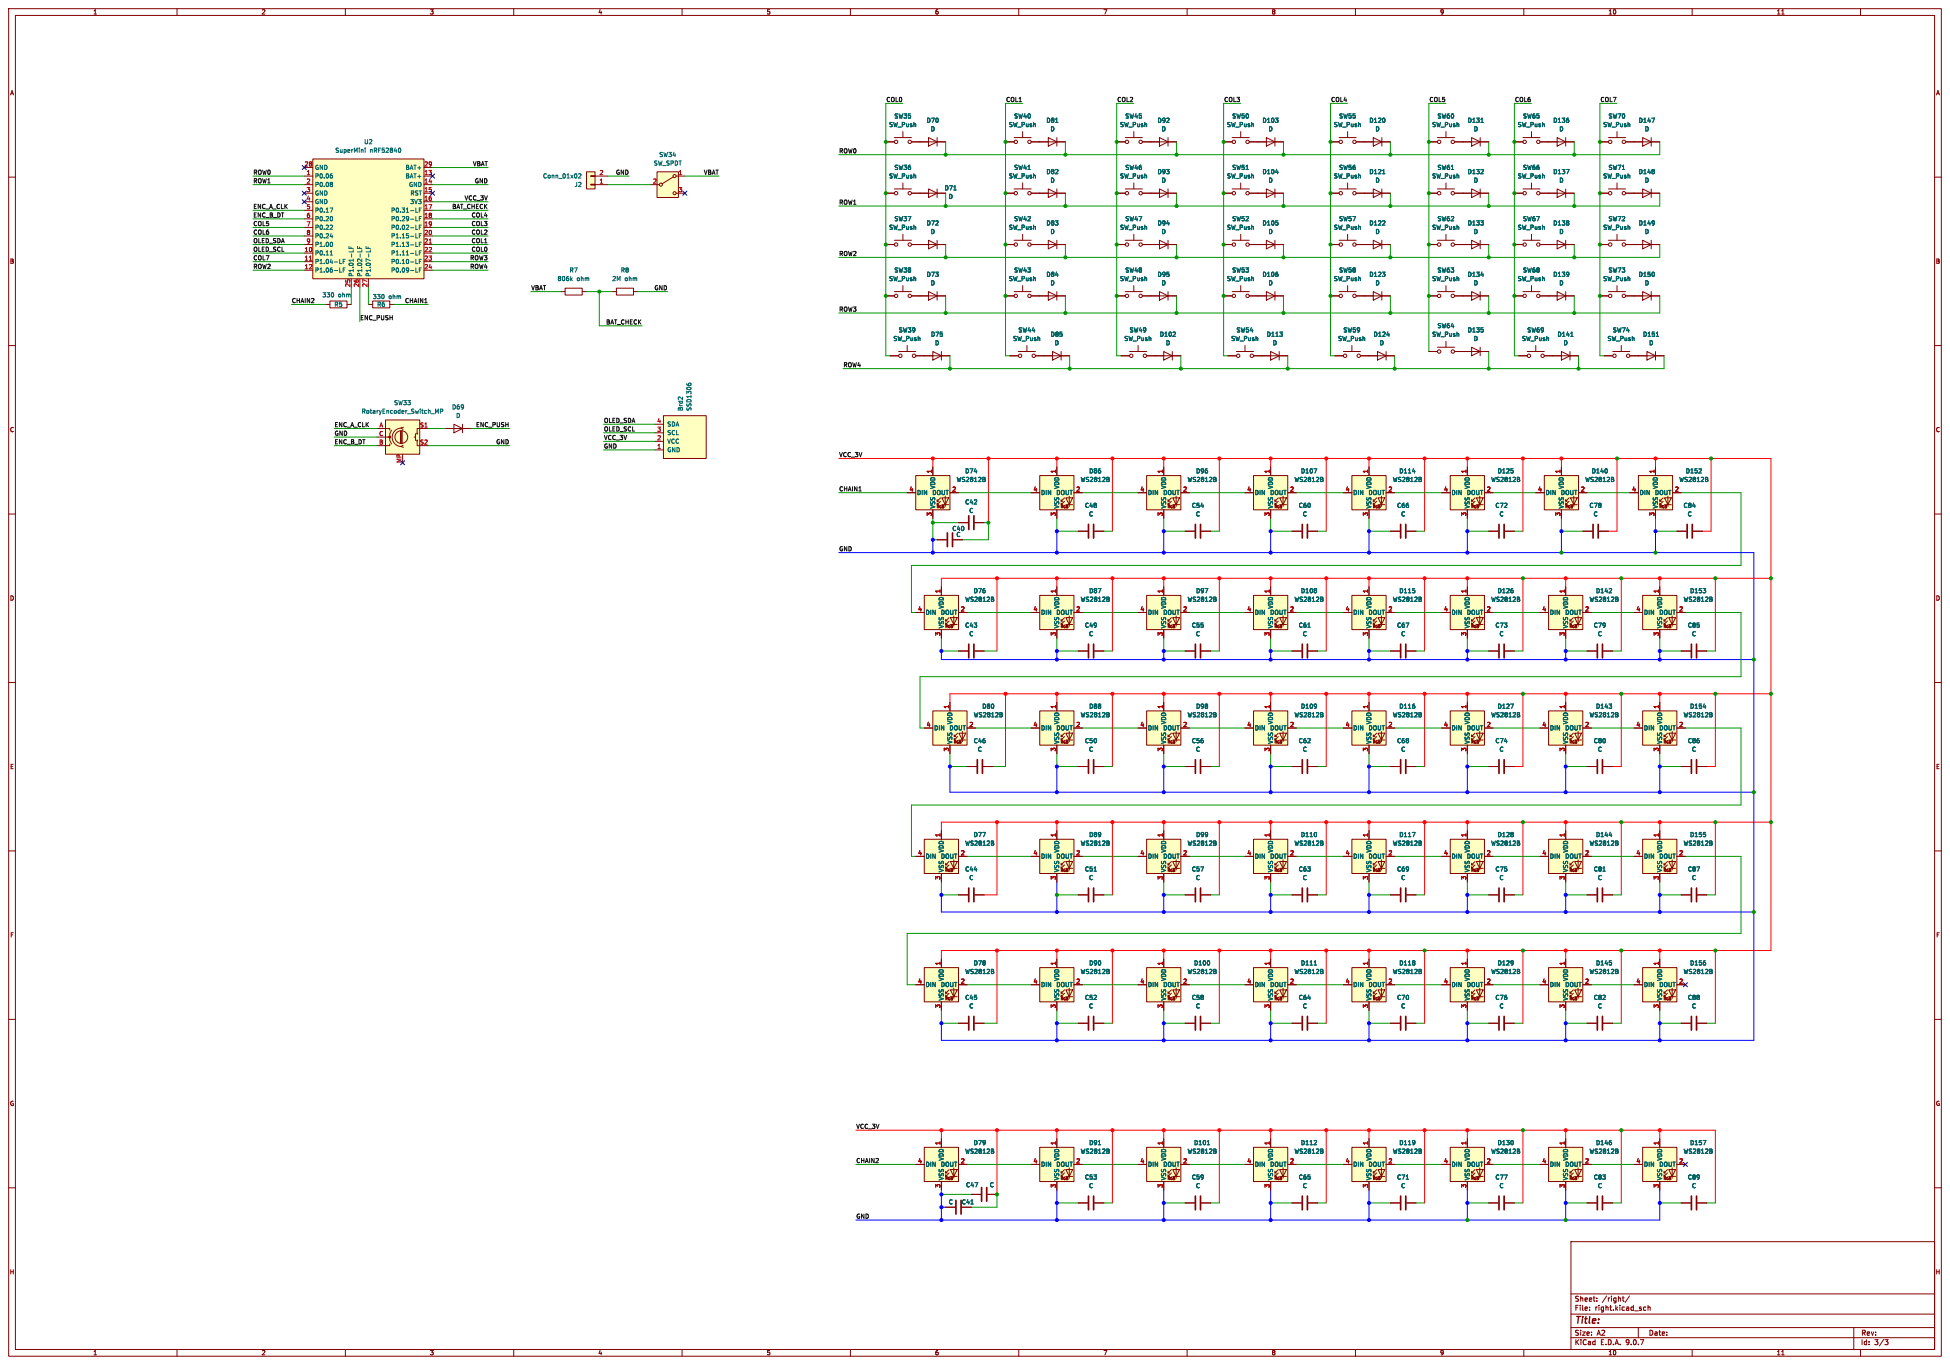
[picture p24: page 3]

Id: 3/3 Title: File: right.kicad_sch Sheet: /right/

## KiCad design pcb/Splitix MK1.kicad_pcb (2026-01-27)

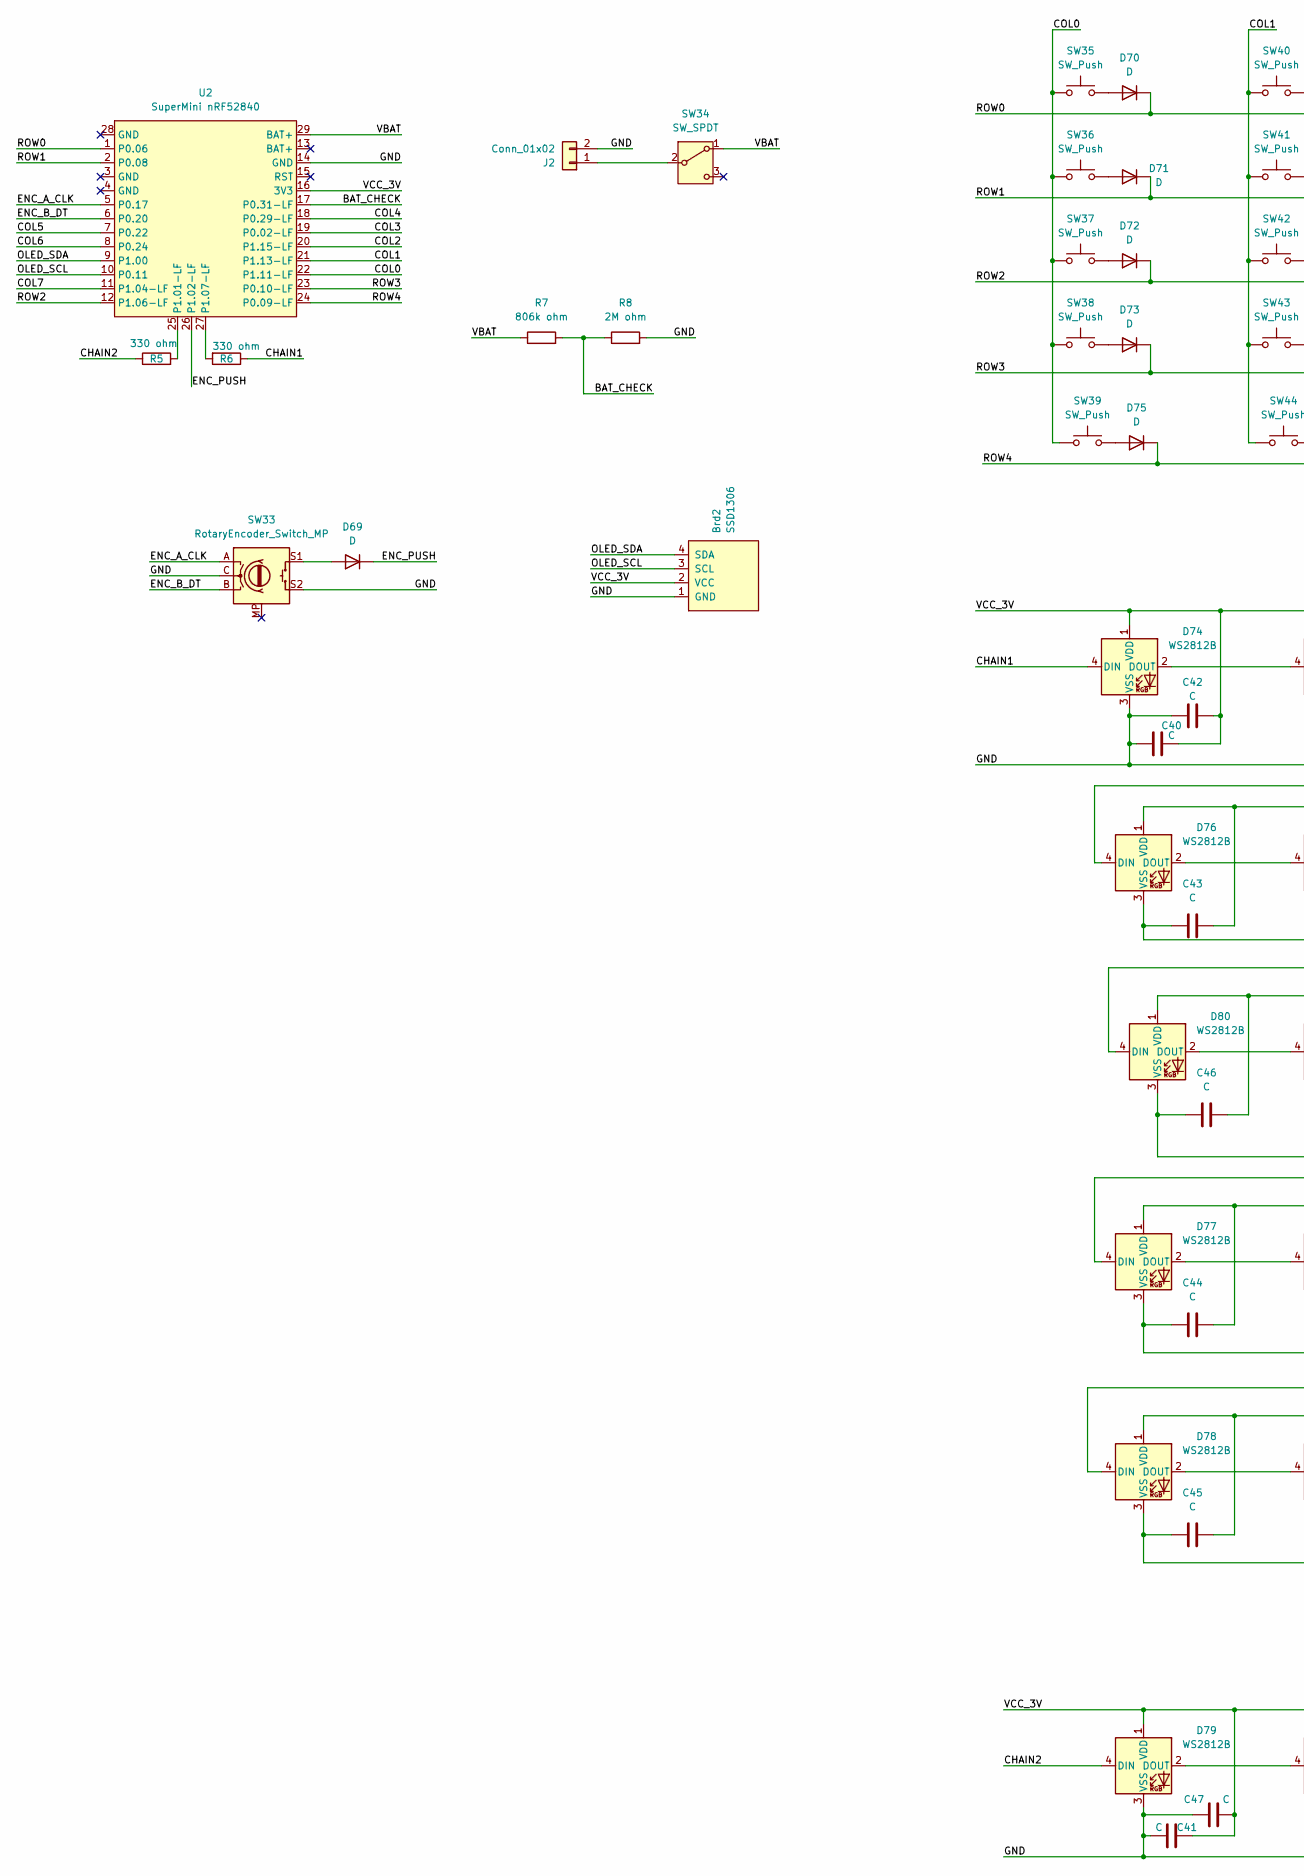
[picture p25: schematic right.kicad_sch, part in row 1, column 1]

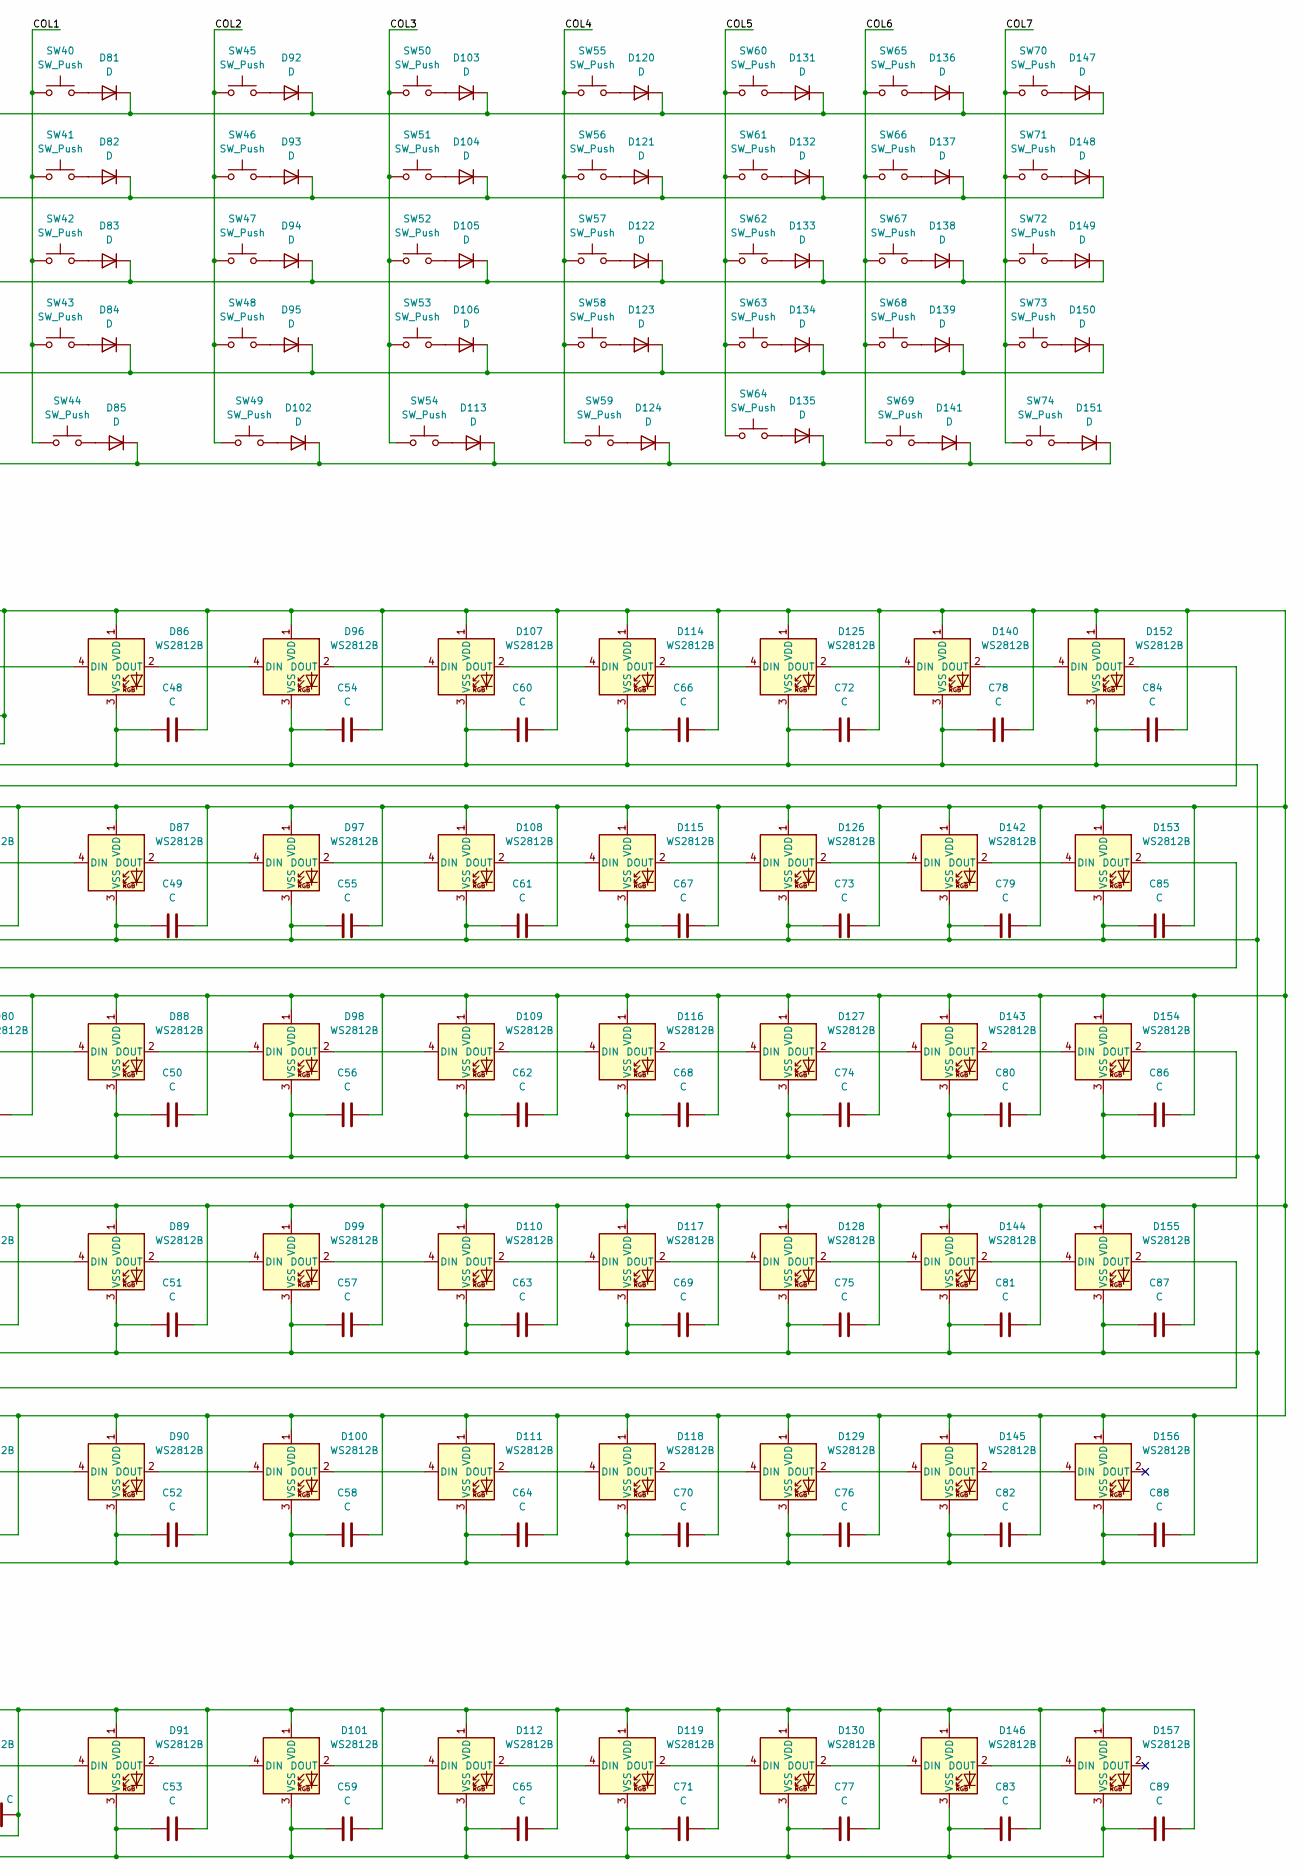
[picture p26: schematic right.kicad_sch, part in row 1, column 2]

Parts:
Brd2: SSD1306; 128x64OLED
C40, C41, C42, C43, C44, C45, C46, C47, C48, C49, C50, C51, C52, C53, C54, C55, C56, C57, C58, C59, C60, C61, C62, C63, C64, C65, C66, C67, C68, C69, C70, C71, C72, C73, C74, C75, C76, C77, C78, C79, C80, C81, C82, C83, C84, C85, C86, C87, C88, C89: C; C_0805_2012Metric_Pad1.18x1.45mm_HandSolder
D69, D70, D71, D72, D73, D75, D81, D82, D83, D84, D85, D92, D93, D94, D95, D102, D103, D104, D105, D106, D113, D120, D121, D122, D123, D124, D131, D132, D133, D134, D135, D136, D137, D138, D139, D141, D147, D148, D149, D150, D151: D; D_DO-35_SOD27_P7.62mm_Horizontal
D74, D76, D77, D78, D80, D86, D87, D88, D89, D90, D96, D97, D98, D99, D100, D107, D108, D109, D110, D111, D114, D115, D116, D117, D118, D125, D126, D127, D128, D129, D140, D142, D143, D144, D145, D152, D153, D154, D155, D156: WS2812B; WS2812B_5050_reversed_SMD_edge
D79, D91, D101, D112, D119, D130, D146, D157: WS2812B; WS2812B_5050_reversed_SMD_strip
J2: Conn_01x02; PinHeader_1x02_P2.54mm_Vertical
R5, R6: 330 ohm; R_Axial_DIN0207_L6.3mm_D2.5mm_P7.62mm_Horizontal
R7: 806k ohm; R_Axial_DIN0207_L6.3mm_D2.5mm_P7.62mm_Horizontal
R8: 2M ohm; R_Axial_DIN0207_L6.3mm_D2.5mm_P7.62mm_Horizontal
SW33: RotaryEncoder_Switch_MP; RotaryEncoder_Alps_EC11E-Switch_Vertical_H20mm_CircularMoun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
SW34: SW_SPDT; PinHeader_1x03_P2.54mm_Vertical
SW35, SW36, SW37, SW38, SW40, SW41, SW42, SW43, SW45, SW46, SW47, SW48, SW49, SW50, SW51, SW52, SW53, SW54, SW55, SW56, SW57, SW58, SW59, SW60, SW61, SW62, SW64, SW66, SW68, SW69, SW70, SW72, SW73, SW74: SW_Push; SW_MX_HS_KS-2P02B01-01_1u
SW39: SW_Push; SW_MX_HS_KS-2P02B01-01_2.75u
SW44: SW_Push; SW_MX_HS_KS-2P02B01-01_1.25u
SW63: SW_Push; SW_MX_HS_KS-2P02B01-01_1.75u
SW65: SW_Push; SW_MX_HS_KS-2P02B01-01_2u
SW67: SW_Push; SW_MX_HS_KS-2P02B01-01_2.25u
SW71: SW_Push; SW_MX_HS_KS-2P02B01-01_1.5u
U2: SuperMini nRF52840; SuperMini_nRF52840_AH_USBup

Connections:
/right/BAT_CHECK: R7.2, R8.1, U2.17 (P0.31-LF)
/right/CHAIN1: D74.4 (DIN), R6.1
/right/CHAIN2: D79.4 (DIN), R5.1
/right/COL0: SW35.1, SW36.1, SW37.1, SW38.1, SW39.1, U2.22 (P1.11-LF)
/right/COL1: SW40.1, SW41.1, SW42.1, SW43.1, SW44.1, U2.21 (P1.13-LF)
/right/COL2: SW45.1, SW46.1, SW47.1, SW48.1, SW49.1, U2.20 (P1.15-LF)
/right/COL3: SW50.1, SW51.1, SW52.1, SW53.1, SW54.1, U2.19 (P0.02-LF)
/right/COL4: SW55.1, SW56.1, SW57.1, SW58.1, SW59.1, U2.18 (P0.29-LF)
/right/COL5: SW60.1, SW61.1, SW62.1, SW63.1, SW64.1, U2.7 (P0.22)
/right/COL6: SW65.1, SW66.1, SW67.1, SW68.1, SW69.1, U2.8 (P0.24)
/right/COL7: SW70.1, SW71.1, SW72.1, SW73.1, SW74.1, U2.11 (P1.04-LF)
/right/ENC_A_CLK: SW33.A, U2.5 (P0.17)
/right/ENC_B_DT: SW33.B, U2.6 (P0.20)
/right/ENC_PUSH: D69.1 (K), U2.26 (P1.02-LF)
/right/GND: Brd2.1 (GND), C40.1, C41.1, C42.1, C43.1, C44.1, C45.1, C46.1, C47.1, C48.1, C49.1, C50.1, C51.1, C52.1, C53.1, C54.1, C55.1, C56.1, C57.1, C58.1, C59.1, C60.1, C61.1, C62.1, C63.1, C64.1, C65.1, C66.1, C67.1, C68.1, C69.1, C70.1, C71.1, C72.1, C73.1, C74.1, C75.1, C76.1, C77.1, C78.1, C79.1, C80.1, C81.1, C82.1, C83.1, C84.1, C85.1, C86.1, C87.1, C88.1, C89.1, D74.3 (VSS), D76.3 (VSS), D77.3 (VSS), D78.3 (VSS), D79.3 (VSS), D80.3 (VSS), D86.3 (VSS), D87.3 (VSS), D88.3 (VSS), D89.3 (VSS), D90.3 (VSS), D91.3 (VSS), D96.3 (VSS), D97.3 (VSS), D98.3 (VSS), D99.3 (VSS), D100.3 (VSS), D101.3 (VSS), D107.3 (VSS), D108.3 (VSS), D109.3 (VSS), D110.3 (VSS), D111.3 (VSS), D112.3 (VSS), D114.3 (VSS), D115.3 (VSS), D116.3 (VSS), D117.3 (VSS), D118.3 (VSS), D119.3 (VSS), D125.3 (VSS), D126.3 (VSS), D127.3 (VSS), D128.3 (VSS), D129.3 (VSS), D130.3 (VSS), D140.3 (VSS), D142.3 (VSS), D143.3 (VSS), D144.3 (VSS), D145.3 (VSS), D146.3 (VSS), D152.3 (VSS), D153.3 (VSS), D154.3 (VSS), D155.3 (VSS), D156.3 (VSS), D157.3 (VSS), J2.2, R8.2, SW33.C, SW33.S2, U2.14 (GND)
/right/OLED_SCL: Brd2.3 (SCL), U2.10 (P0.11)
/right/OLED_SDA: Brd2.4 (SDA), U2.9 (P1.00)
/right/ROW0: D70.1 (K), D81.1 (K), D92.1 (K), D103.1 (K), D120.1 (K), D131.1 (K), D136.1 (K), D147.1 (K), U2.1 (P0.06)
/right/ROW1: D71.1 (K), D82.1 (K), D93.1 (K), D104.1 (K), D121.1 (K), D132.1 (K), D137.1 (K), D148.1 (K), U2.2 (P0.08)
/right/ROW2: D72.1 (K), D83.1 (K), D94.1 (K), D105.1 (K), D122.1 (K), D133.1 (K), D138.1 (K), D149.1 (K), U2.12 (P1.06-LF)
/right/ROW3: D73.1 (K), D84.1 (K), D95.1 (K), D106.1 (K), D123.1 (K), D134.1 (K), D139.1 (K), D150.1 (K), U2.23 (P0.10-LF)
/right/ROW4: D75.1 (K), D85.1 (K), D102.1 (K), D113.1 (K), D124.1 (K), D135.1 (K), D141.1 (K), D151.1 (K), U2.24 (P0.09-LF)
/right/VBAT: R7.1, SW34.1 (A), U2.29 (BAT+)
/right/VCC_3V: Brd2.2 (VCC), C40.2, C41.2, C42.2, C43.2, C44.2, C45.2, C46.2, C47.2, C48.2, C49.2, C50.2, C51.2, C52.2, C53.2, C54.2, C55.2, C56.2, C57.2, C58.2, C59.2, C60.2, C61.2, C62.2, C63.2, C64.2, C65.2, C66.2, C67.2, C68.2, C69.2, C70.2, C71.2, C72.2, C73.2, C74.2, C75.2, C76.2, C77.2, C78.2, C79.2, C80.2, C81.2, C82.2, C83.2, C84.2, C85.2, C86.2, C87.2, C88.2, C89.2, D74.1 (VDD), D76.1 (VDD), D77.1 (VDD), D78.1 (VDD), D79.1 (VDD), D80.1 (VDD), D86.1 (VDD), D87.1 (VDD), D88.1 (VDD), D89.1 (VDD), D90.1 (VDD), D91.1 (VDD), D96.1 (VDD), D97.1 (VDD), D98.1 (VDD), D99.1 (VDD), D100.1 (VDD), D101.1 (VDD), D107.1 (VDD), D108.1 (VDD), D109.1 (VDD), D110.1 (VDD), D111.1 (VDD), D112.1 (VDD), D114.1 (VDD), D115.1 (VDD), D116.1 (VDD), D117.1 (VDD), D118.1 (VDD), D119.1 (VDD), D125.1 (VDD), D126.1 (VDD), D127.1 (VDD), D128.1 (VDD), D129.1 (VDD), D130.1 (VDD), D140.1 (VDD), D142.1 (VDD), D143.1 (VDD), D144.1 (VDD), D145.1 (VDD), D146.1 (VDD), D152.1 (VDD), D153.1 (VDD), D154.1 (VDD), D155.1 (VDD), D156.1 (VDD), D157.1 (VDD), U2.16 (3V3)
unnamed: D69.2 (A), SW33.S1
unnamed: D70.2 (A), SW35.2
unnamed: D71.2 (A), SW36.2
unnamed: D72.2 (A), SW37.2
unnamed: D73.2 (A), SW38.2
unnamed: D74.2 (DOUT), D86.4 (DIN)
unnamed: D75.2 (A), SW39.2
unnamed: D76.2 (DOUT), D87.4 (DIN)
unnamed: D77.2 (DOUT), D89.4 (DIN)
unnamed: D78.2 (DOUT), D90.4 (DIN)
unnamed: D79.2 (DOUT), D91.4 (DIN)
unnamed: D80.2 (DOUT), D88.4 (DIN)
unnamed: D81.2 (A), SW40.2
unnamed: D82.2 (A), SW41.2
unnamed: D83.2 (A), SW42.2
unnamed: D84.2 (A), SW43.2
unnamed: D85.2 (A), SW44.2
unnamed: D86.2 (DOUT), D96.4 (DIN)
unnamed: D87.2 (DOUT), D97.4 (DIN)
unnamed: D88.2 (DOUT), D98.4 (DIN)
unnamed: D89.2 (DOUT), D99.4 (DIN)
unnamed: D92.2 (A), SW45.2
unnamed: D93.2 (A), SW46.2
unnamed: D94.2 (A), SW47.2
unnamed: D95.2 (A), SW48.2
unnamed: D90.2 (DOUT), D100.4 (DIN)
unnamed: D100.2 (DOUT), D111.4 (DIN)
unnamed: D91.2 (DOUT), D101.4 (DIN)
unnamed: D101.2 (DOUT), D112.4 (DIN)
unnamed: D102.2 (A), SW49.2
unnamed: D103.2 (A), SW50.2
unnamed: D104.2 (A), SW51.2
unnamed: D105.2 (A), SW52.2
unnamed: D106.2 (A), SW53.2
unnamed: D96.2 (DOUT), D107.4 (DIN)
unnamed: D107.2 (DOUT), D114.4 (DIN)
unnamed: D97.2 (DOUT), D108.4 (DIN)
unnamed: D108.2 (DOUT), D115.4 (DIN)
unnamed: D98.2 (DOUT), D109.4 (DIN)
unnamed: D109.2 (DOUT), D116.4 (DIN)
unnamed: D99.2 (DOUT), D110.4 (DIN)
unnamed: D110.2 (DOUT), D117.4 (DIN)
unnamed: D111.2 (DOUT), D118.4 (DIN)
unnamed: D112.2 (DOUT), D119.4 (DIN)
unnamed: D113.2 (A), SW54.2
unnamed: D114.2 (DOUT), D125.4 (DIN)
unnamed: D115.2 (DOUT), D126.4 (DIN)
unnamed: D116.2 (DOUT), D127.4 (DIN)
unnamed: D117.2 (DOUT), D128.4 (DIN)
unnamed: D118.2 (DOUT), D129.4 (DIN)
unnamed: D119.2 (DOUT), D130.4 (DIN)
unnamed: D120.2 (A), SW55.2
unnamed: D121.2 (A), SW56.2
unnamed: D122.2 (A), SW57.2
unnamed: D123.2 (A), SW58.2
unnamed: D124.2 (A), SW59.2
unnamed: D125.2 (DOUT), D140.4 (DIN)
unnamed: D126.2 (DOUT), D142.4 (DIN)
unnamed: D127.2 (DOUT), D143.4 (DIN)
unnamed: D128.2 (DOUT), D144.4 (DIN)
unnamed: D129.2 (DOUT), D145.4 (DIN)
unnamed: D130.2 (DOUT), D146.4 (DIN)
unnamed: D131.2 (A), SW60.2
unnamed: D132.2 (A), SW61.2
unnamed: D133.2 (A), SW62.2
unnamed: D134.2 (A), SW63.2
unnamed: D135.2 (A), SW64.2
unnamed: D136.2 (A), SW65.2
unnamed: D137.2 (A), SW66.2
unnamed: D138.2 (A), SW67.2
unnamed: D139.2 (A), SW68.2
unnamed: D140.2 (DOUT), D152.4 (DIN)
unnamed: D141.2 (A), SW69.2
unnamed: D142.2 (DOUT), D153.4 (DIN)
unnamed: D143.2 (DOUT), D154.4 (DIN)
unnamed: D144.2 (DOUT), D155.4 (DIN)
unnamed: D145.2 (DOUT), D156.4 (DIN)
unnamed: D146.2 (DOUT), D157.4 (DIN)
unnamed: D147.2 (A), SW70.2
unnamed: D148.2 (A), SW71.2
unnamed: D149.2 (A), SW72.2
unnamed: D150.2 (A), SW73.2
unnamed: D151.2 (A), SW74.2
unnamed: D76.4 (DIN), D152.2 (DOUT)
unnamed: D80.4 (DIN), D153.2 (DOUT)
unnamed: D77.4 (DIN), D154.2 (DOUT)
unnamed: D78.4 (DIN), D155.2 (DOUT)
unnamed: J2.1, SW34.2 (B)
unnamed: R5.2, U2.25 (P1.01-LF)
unnamed: R6.2, U2.27 (P1.07-LF)

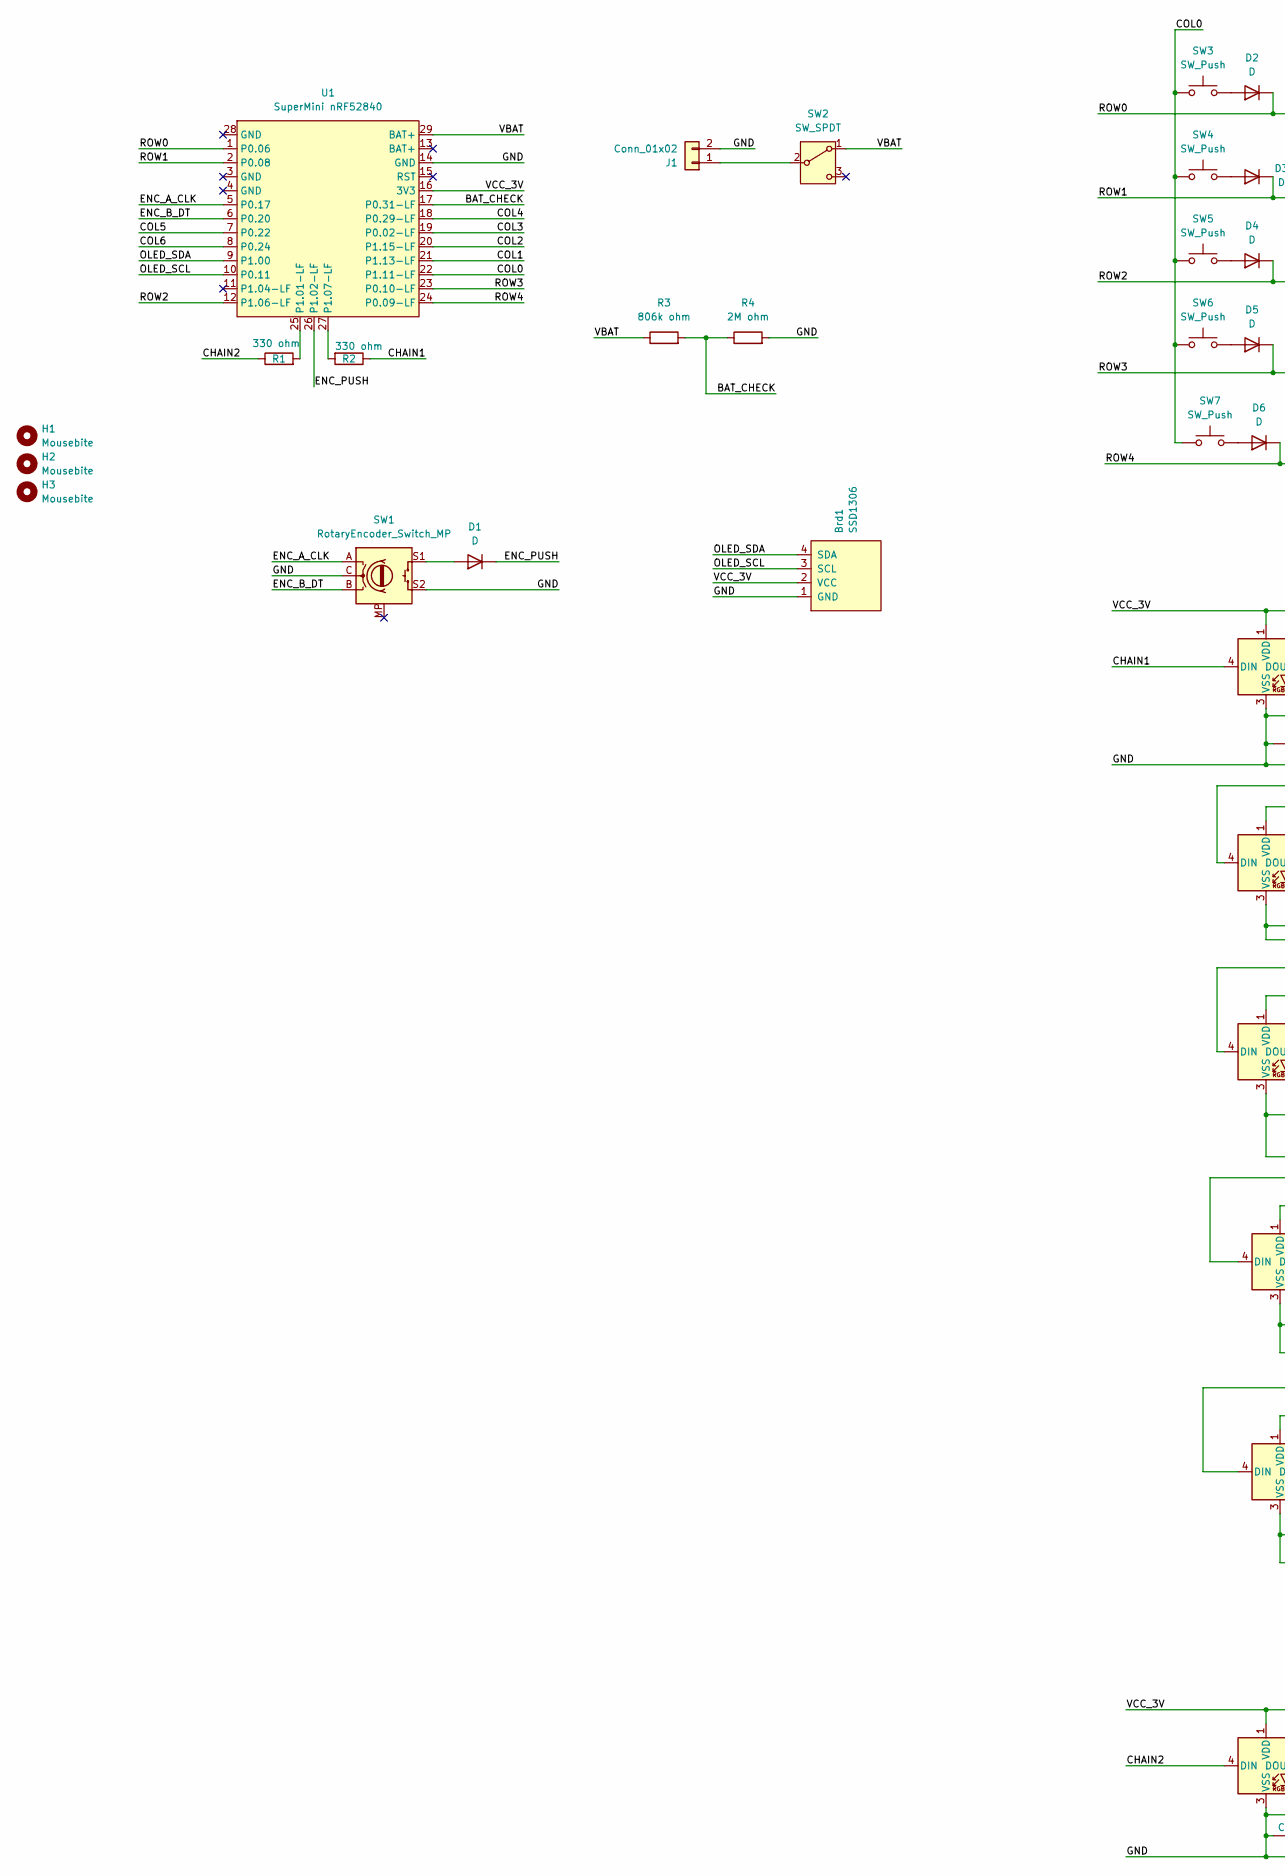
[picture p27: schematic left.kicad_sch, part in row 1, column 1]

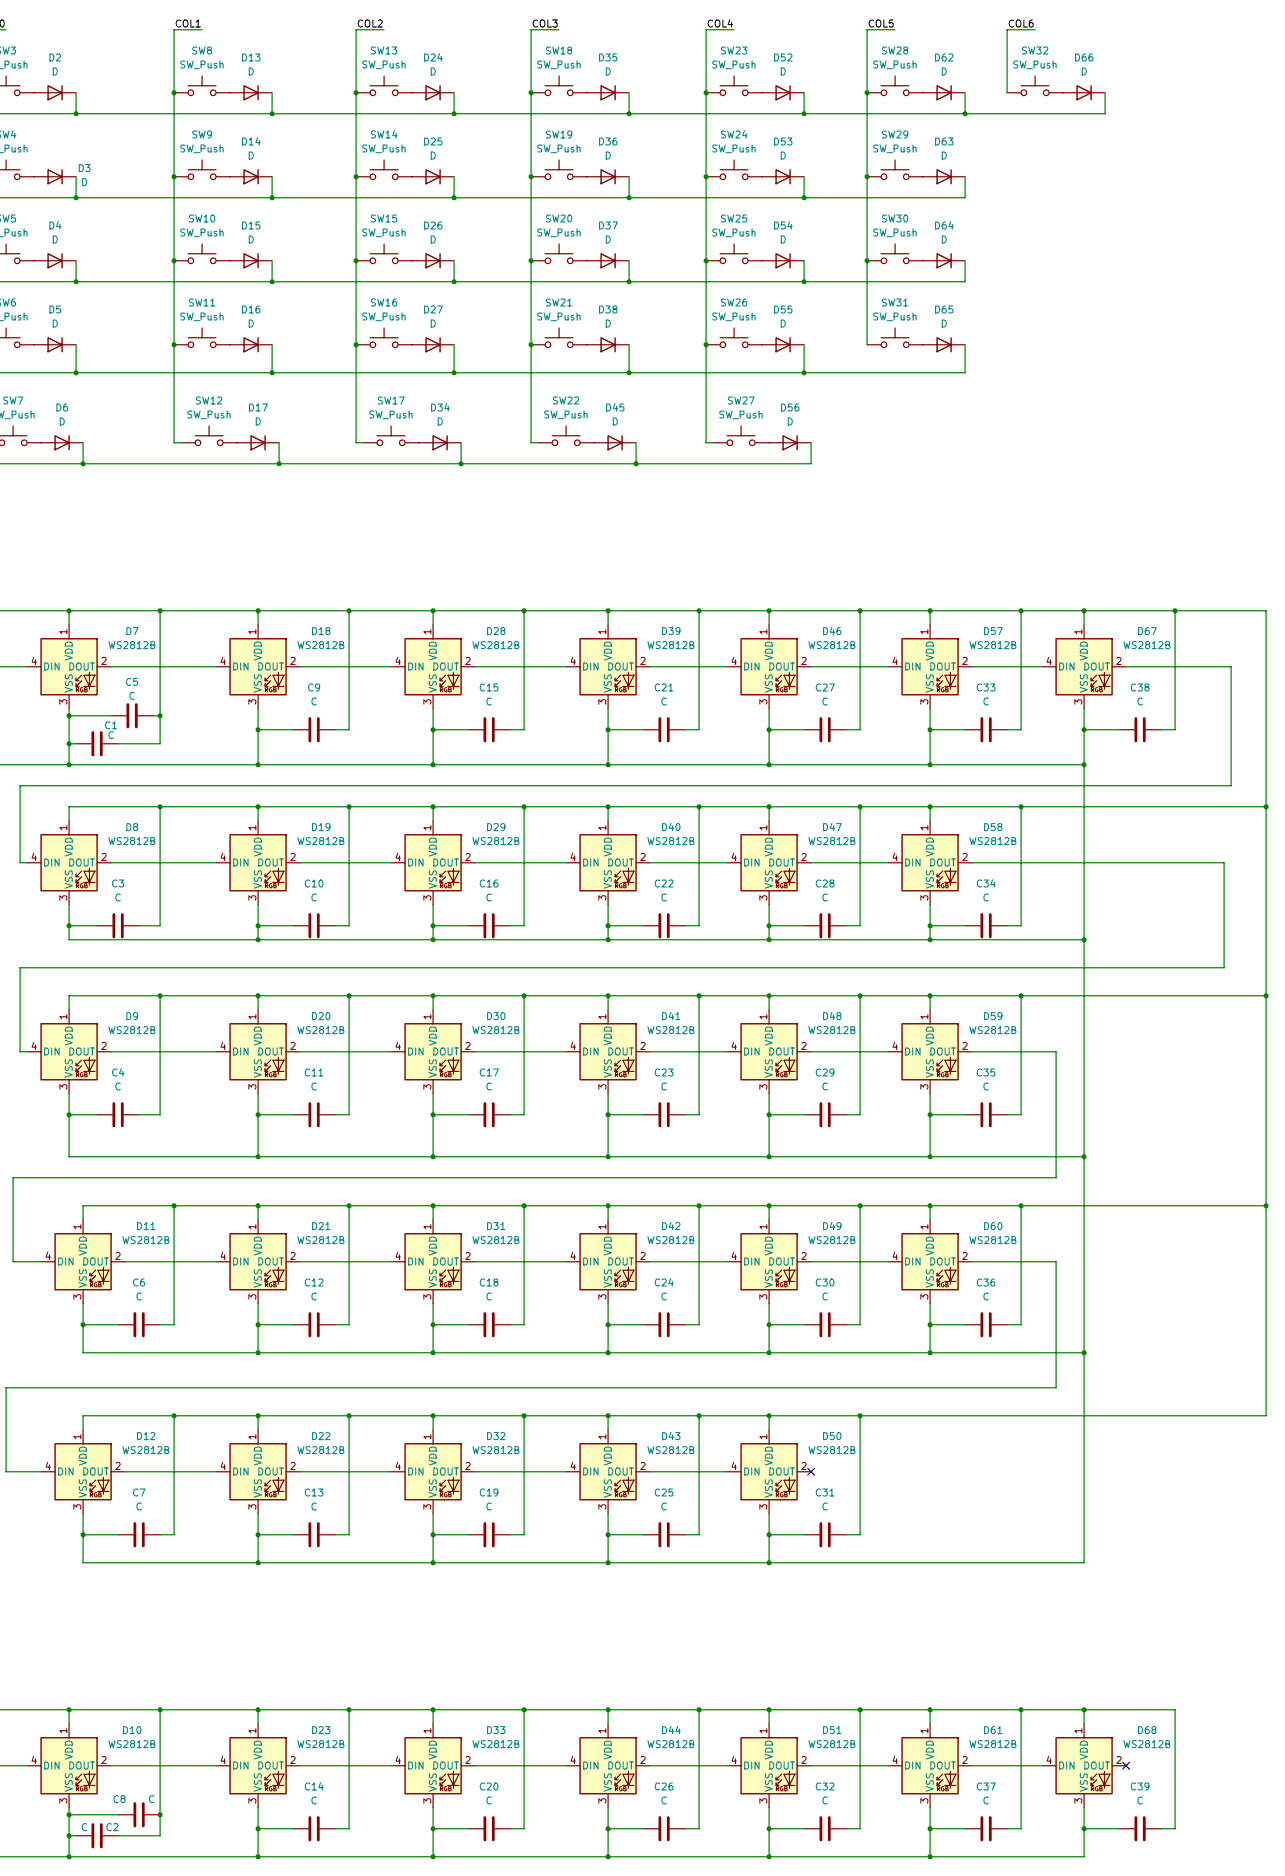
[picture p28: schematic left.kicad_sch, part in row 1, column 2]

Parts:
Brd1: SSD1306; 128x64OLED
C1, C2, C3, C4, C5, C6, C7, C8, C9, C10, C11, C12, C13, C14, C15, C16, C17, C18, C19, C20, C21, C22, C23, C24, C25, C26, C27, C28, C29, C30, C31, C32, C33, C34, C35, C36, C37, C38, C39: C; C_0805_2012Metric_Pad1.18x1.45mm_HandSolder
D1, D2, D3, D4, D5, D6, D13, D14, D15, D16, D17, D24, D25, D26, D27, D34, D35, D36, D37, D38, D45, D52, D53, D54, D55, D56, D62, D63, D64, D65, D66: D; D_DO-35_SOD27_P7.62mm_Horizontal
D7, D8, D9, D11, D12, D18, D19, D20, D21, D22, D28, D29, D30, D31, D32, D39, D40, D41, D42, D43, D46, D47, D48, D49, D50, D57, D58, D59, D60, D67: WS2812B; WS2812B_5050_reversed_SMD_edge
D10, D23, D33, D44, D51, D61, D68: WS2812B; WS2812B_5050_reversed_SMD_strip
H1, H2, H3: Mousebite; MouseBite-Slot_2.0x4.5mm_outset_D0.5mm_P0.85mm_7h
J1: Conn_01x02; PinHeader_1x02_P2.54mm_Vertical
R1, R2: 330 ohm; R_Axial_DIN0207_L6.3mm_D2.5mm_P7.62mm_Horizontal
R3: 806k ohm; R_Axial_DIN0207_L6.3mm_D2.5mm_P7.62mm_Horizontal
R4: 2M ohm; R_Axial_DIN0207_L6.3mm_D2.5mm_P7.62mm_Horizontal
SW1: RotaryEncoder_Switch_MP; RotaryEncoder_Alps_EC11E-Switch_Vertical_H20mm_CircularMoun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
SW2: SW_SPDT; PinHeader_1x03_P2.54mm_Vertical
SW3, SW8, SW9, SW10, SW11, SW13, SW14, SW15, SW16, SW18, SW19, SW20, SW21, SW23, SW24, SW25, SW26, SW28, SW29, SW30, SW31, SW32: SW_Push; SW_MX_HS_KS-2P02B01-01_1u
SW4: SW_Push; SW_MX_HS_KS-2P02B01-01_1.5u
SW5: SW_Push; SW_MX_HS_KS-2P02B01-01_1.75u
SW6: SW_Push; SW_MX_HS_KS-2P02B01-01_2.25u
SW7, SW12, SW17, SW22: SW_Push; SW_MX_HS_KS-2P02B01-01_1.25u
SW27: SW_Push; SW_MX_HS_KS-2P02B01-01_2u
U1: SuperMini nRF52840; SuperMini_nRF52840_AH_USBup

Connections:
/left/BAT_CHECK: R3.2, R4.1, U1.17 (P0.31-LF)
/left/CHAIN1: D7.4 (DIN), R2.1
/left/CHAIN2: D10.4 (DIN), R1.1
/left/COL0: SW3.1, SW4.1, SW5.1, SW6.1, SW7.1, U1.22 (P1.11-LF)
/left/COL1: SW8.1, SW9.1, SW10.1, SW11.1, SW12.1, U1.21 (P1.13-LF)
/left/COL2: SW13.1, SW14.1, SW15.1, SW16.1, SW17.1, U1.20 (P1.15-LF)
/left/COL3: SW18.1, SW19.1, SW20.1, SW21.1, SW22.1, U1.19 (P0.02-LF)
/left/COL4: SW23.1, SW24.1, SW25.1, SW26.1, SW27.1, U1.18 (P0.29-LF)
/left/COL5: SW28.1, SW29.1, SW30.1, SW31.1, U1.7 (P0.22)
/left/COL6: SW32.1, U1.8 (P0.24)
/left/ENC_A_CLK: SW1.A, U1.5 (P0.17)
/left/ENC_B_DT: SW1.B, U1.6 (P0.20)
/left/ENC_PUSH: D1.1 (K), U1.26 (P1.02-LF)
/left/GND: Brd1.1 (GND), C1.1, C2.1, C3.1, C4.1, C5.1, C6.1, C7.1, C8.1, C9.1, C10.1, C11.1, C12.1, C13.1, C14.1, C15.1, C16.1, C17.1, C18.1, C19.1, C20.1, C21.1, C22.1, C23.1, C24.1, C25.1, C26.1, C27.1, C28.1, C29.1, C30.1, C31.1, C32.1, C33.1, C34.1, C35.1, C36.1, C37.1, C38.1, C39.1, D7.3 (VSS), D8.3 (VSS), D9.3 (VSS), D10.3 (VSS), D11.3 (VSS), D12.3 (VSS), D18.3 (VSS), D19.3 (VSS), D20.3 (VSS), D21.3 (VSS), D22.3 (VSS), D23.3 (VSS), D28.3 (VSS), D29.3 (VSS), D30.3 (VSS), D31.3 (VSS), D32.3 (VSS), D33.3 (VSS), D39.3 (VSS), D40.3 (VSS), D41.3 (VSS), D42.3 (VSS), D43.3 (VSS), D44.3 (VSS), D46.3 (VSS), D47.3 (VSS), D48.3 (VSS), D49.3 (VSS), D50.3 (VSS), D51.3 (VSS), D57.3 (VSS), D58.3 (VSS), D59.3 (VSS), D60.3 (VSS), D61.3 (VSS), D67.3 (VSS), D68.3 (VSS), J1.2, R4.2, SW1.C, SW1.S2, U1.14 (GND)
/left/OLED_SCL: Brd1.3 (SCL), U1.10 (P0.11)
/left/OLED_SDA: Brd1.4 (SDA), U1.9 (P1.00)
/left/ROW0: D2.1 (K), D13.1 (K), D24.1 (K), D35.1 (K), D52.1 (K), D62.1 (K), D66.1 (K), U1.1 (P0.06)
/left/ROW1: D3.1 (K), D14.1 (K), D25.1 (K), D36.1 (K), D53.1 (K), D63.1 (K), U1.2 (P0.08)
/left/ROW2: D4.1 (K), D15.1 (K), D26.1 (K), D37.1 (K), D54.1 (K), D64.1 (K), U1.12 (P1.06-LF)
/left/ROW3: D5.1 (K), D16.1 (K), D27.1 (K), D38.1 (K), D55.1 (K), D65.1 (K), U1.23 (P0.10-LF)
/left/ROW4: D6.1 (K), D17.1 (K), D34.1 (K), D45.1 (K), D56.1 (K), U1.24 (P0.09-LF)
/left/VBAT: R3.1, SW2.1 (A), U1.29 (BAT+)
/left/VCC_3V: Brd1.2 (VCC), C1.2, C2.2, C3.2, C4.2, C5.2, C6.2, C7.2, C8.2, C9.2, C10.2, C11.2, C12.2, C13.2, C14.2, C15.2, C16.2, C17.2, C18.2, C19.2, C20.2, C21.2, C22.2, C23.2, C24.2, C25.2, C26.2, C27.2, C28.2, C29.2, C30.2, C31.2, C32.2, C33.2, C34.2, C35.2, C36.2, C37.2, C38.2, C39.2, D7.1 (VDD), D8.1 (VDD), D9.1 (VDD), D10.1 (VDD), D11.1 (VDD), D12.1 (VDD), D18.1 (VDD), D19.1 (VDD), D20.1 (VDD), D21.1 (VDD), D22.1 (VDD), D23.1 (VDD), D28.1 (VDD), D29.1 (VDD), D30.1 (VDD), D31.1 (VDD), D32.1 (VDD), D33.1 (VDD), D39.1 (VDD), D40.1 (VDD), D41.1 (VDD), D42.1 (VDD), D43.1 (VDD), D44.1 (VDD), D46.1 (VDD), D47.1 (VDD), D48.1 (VDD), D49.1 (VDD), D50.1 (VDD), D51.1 (VDD), D57.1 (VDD), D58.1 (VDD), D59.1 (VDD), D60.1 (VDD), D61.1 (VDD), D67.1 (VDD), D68.1 (VDD), U1.16 (3V3)
unnamed: D1.2 (A), SW1.S1
unnamed: D2.2 (A), SW3.2
unnamed: D3.2 (A), SW4.2
unnamed: D4.2 (A), SW5.2
unnamed: D5.2 (A), SW6.2
unnamed: D6.2 (A), SW7.2
unnamed: D10.2 (DOUT), D23.4 (DIN)
unnamed: D11.4 (DIN), D59.2 (DOUT)
unnamed: D11.2 (DOUT), D21.4 (DIN)
unnamed: D12.4 (DIN), D60.2 (DOUT)
unnamed: D12.2 (DOUT), D22.4 (DIN)
unnamed: D13.2 (A), SW8.2
unnamed: D14.2 (A), SW9.2
unnamed: D15.2 (A), SW10.2
unnamed: D16.2 (A), SW11.2
unnamed: D17.2 (A), SW12.2
unnamed: D7.2 (DOUT), D18.4 (DIN)
unnamed: D18.2 (DOUT), D28.4 (DIN)
unnamed: D8.2 (DOUT), D19.4 (DIN)
unnamed: D19.2 (DOUT), D29.4 (DIN)
unnamed: D9.2 (DOUT), D20.4 (DIN)
unnamed: D20.2 (DOUT), D30.4 (DIN)
unnamed: D21.2 (DOUT), D31.4 (DIN)
unnamed: D22.2 (DOUT), D32.4 (DIN)
unnamed: D23.2 (DOUT), D33.4 (DIN)
unnamed: D24.2 (A), SW13.2
unnamed: D25.2 (A), SW14.2
unnamed: D26.2 (A), SW15.2
unnamed: D27.2 (A), SW16.2
unnamed: D28.2 (DOUT), D39.4 (DIN)
unnamed: D29.2 (DOUT), D40.4 (DIN)
unnamed: D30.2 (DOUT), D41.4 (DIN)
unnamed: D31.2 (DOUT), D42.4 (DIN)
unnamed: D32.2 (DOUT), D43.4 (DIN)
unnamed: D33.2 (DOUT), D44.4 (DIN)
unnamed: D34.2 (A), SW17.2
unnamed: D35.2 (A), SW18.2
unnamed: D36.2 (A), SW19.2
unnamed: D37.2 (A), SW20.2
unnamed: D38.2 (A), SW21.2
unnamed: D39.2 (DOUT), D46.4 (DIN)
unnamed: D40.2 (DOUT), D47.4 (DIN)
unnamed: D41.2 (DOUT), D48.4 (DIN)
unnamed: D42.2 (DOUT), D49.4 (DIN)
unnamed: D43.2 (DOUT), D50.4 (DIN)
unnamed: D44.2 (DOUT), D51.4 (DIN)
unnamed: D45.2 (A), SW22.2
unnamed: D46.2 (DOUT), D57.4 (DIN)
unnamed: D47.2 (DOUT), D58.4 (DIN)
unnamed: D48.2 (DOUT), D59.4 (DIN)
unnamed: D49.2 (DOUT), D60.4 (DIN)
unnamed: D51.2 (DOUT), D61.4 (DIN)
unnamed: D52.2 (A), SW23.2
unnamed: D53.2 (A), SW24.2
unnamed: D54.2 (A), SW25.2
unnamed: D55.2 (A), SW26.2
unnamed: D56.2 (A), SW27.2
unnamed: D57.2 (DOUT), D67.4 (DIN)
unnamed: D9.4 (DIN), D58.2 (DOUT)
unnamed: D61.2 (DOUT), D68.4 (DIN)
unnamed: D62.2 (A), SW28.2
unnamed: D63.2 (A), SW29.2
unnamed: D64.2 (A), SW30.2
unnamed: D65.2 (A), SW31.2
unnamed: D66.2 (A), SW32.2
unnamed: D8.4 (DIN), D67.2 (DOUT)
unnamed: J1.1, SW2.2 (B)
unnamed: R1.2, U1.25 (P1.01-LF)
unnamed: R2.2, U1.27 (P1.07-LF)

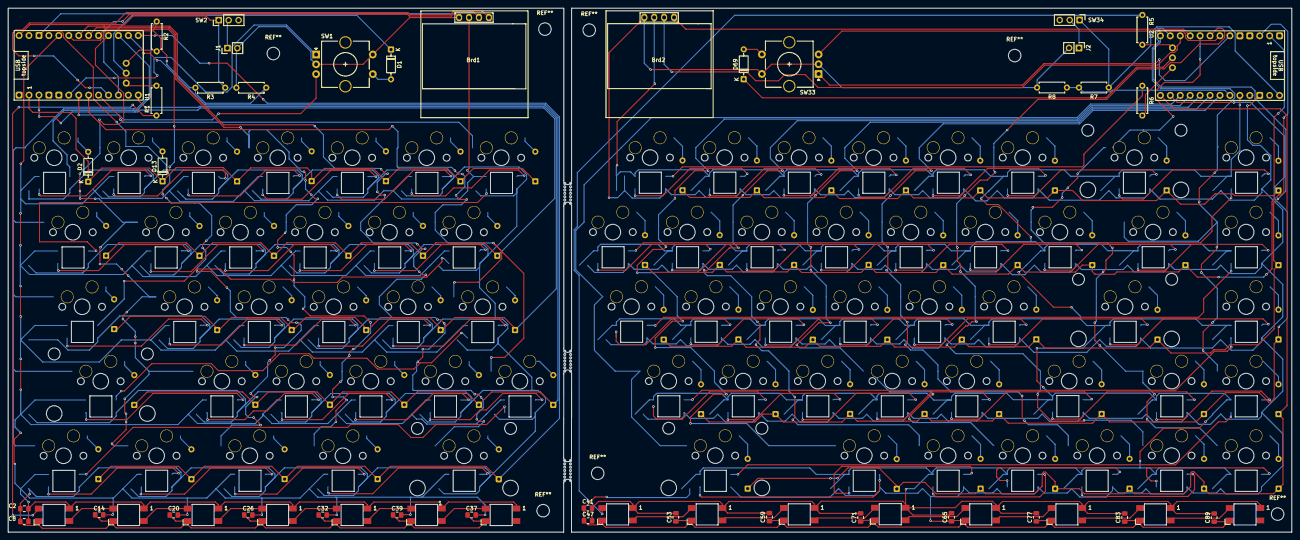
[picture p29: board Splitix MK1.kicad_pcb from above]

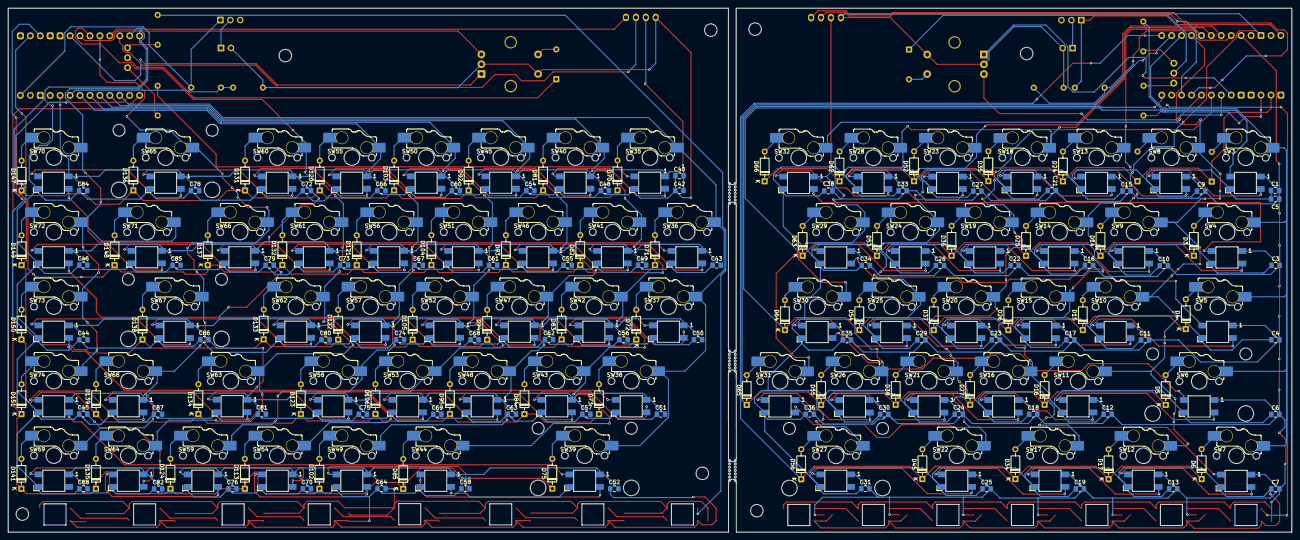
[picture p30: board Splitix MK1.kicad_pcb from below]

Board: 2 copper layers, 328.2 x 134.0 mm, 337 parts (280 on the bottom side), 206 nets.

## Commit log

2026-01-17 cad and 3d files
    [Splitix_MK1_only_case.stl, case_with_threads_only.stl]
2026-01-27 adding pcb files
    [1_01 Table of Contents.kicad_sch, 2_02 Block Diagram.kicad_sch, 3_03 Power IN & MCU GPIOs.kicad_sch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]
2026-01-27 added cad files
2026-03-21 Added BOM from KiCAD
    [Splitix MK1.csv]
2026-03-22 Adding final BOM for Splitix Mark - I
    [BOM.xlsx]
2026-03-24 added printing files
    [full_open_case.stl, left_open_case.3mf, left_open_case.stl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]
2026-03-24 added schematic pdf
2026-03-24 updated BOM
    [BOM.xlsx]
2026-03-26 added assembly files
    [left_assembled.step, right_assembled.step]
2026-03-26 added step files
    [left_open_case.step, right_open_case.step]
2026-03-26 added extra gerbers
2026-03-26 added production files
    [full_open_case.3mf, full_open_case.stl, left_open_case.3mf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]
2026-03-26 updated files
    [case_with_threads_only.stl]
2026-03-26 file/folder cleanup
    [full_open_case.3mf, full_open_case.stl, left_open_case.3mf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]
2026-03-26 file and folder restructure
    [Splitix MK1.csv, Splitix MK1.step]
2026-03-26 added step file format
    [left_open_case.step, right_open_case.step]
